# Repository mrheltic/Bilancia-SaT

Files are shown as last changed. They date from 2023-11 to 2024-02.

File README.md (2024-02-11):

# Bilancia SaT - Gruppo 04

This project uses Arduino and various libraries to create a weighing system with an HX711 load cell amplifier, an LCD display, and a tare button. The program continuously reads the change in weight and displays it on both the Serial Monitor and the LCD screen. We also implemented a tare button to reset the scale to zero when needed.

## Example

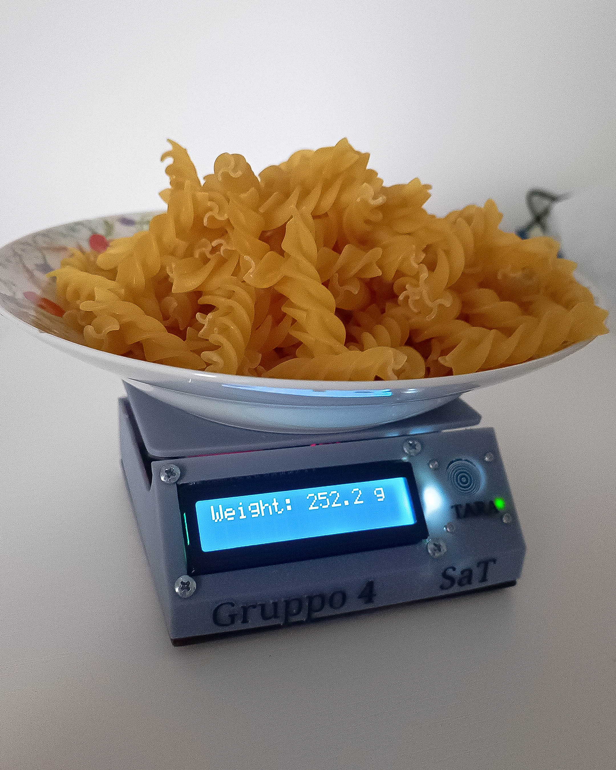
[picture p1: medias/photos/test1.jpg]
Example


## Assembly

https://github.com/mrheltic/Bilancia-SaT/assets/25135341/8b41f5b5-bcb0-4e01-b5df-058aa0fdd161

## Front View

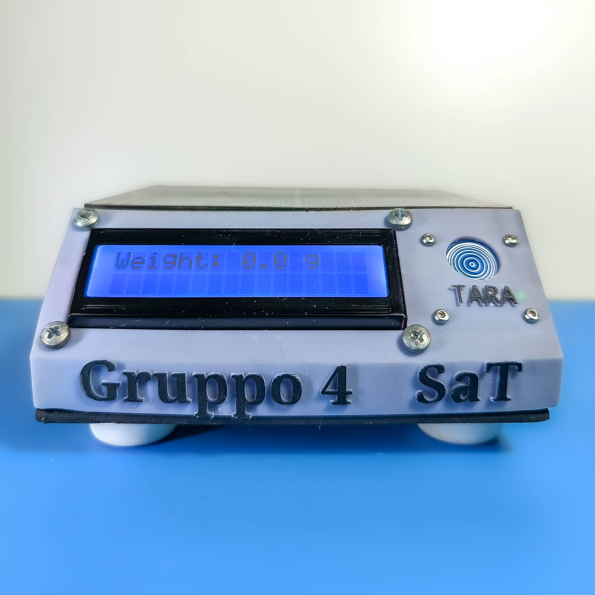
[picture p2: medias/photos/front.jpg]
Front View


## Top View

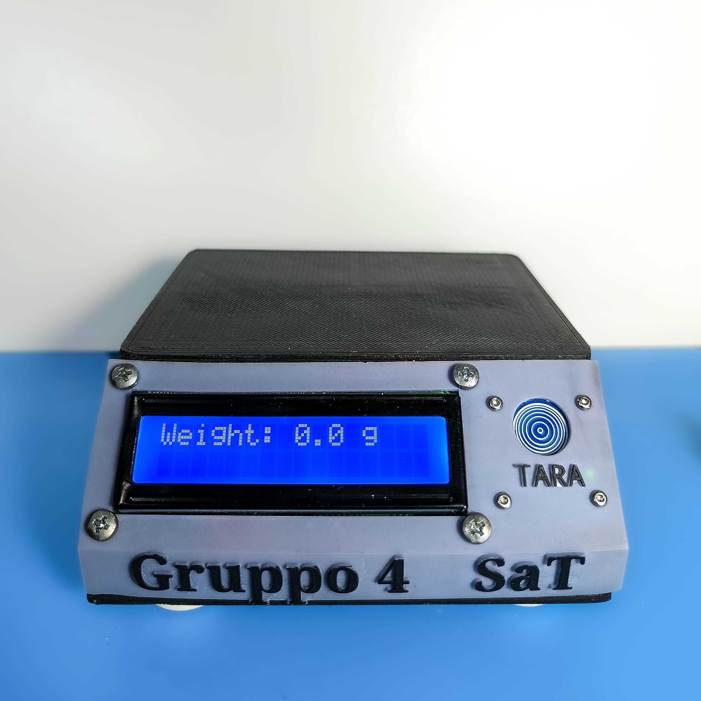
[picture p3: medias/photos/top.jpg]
Top View

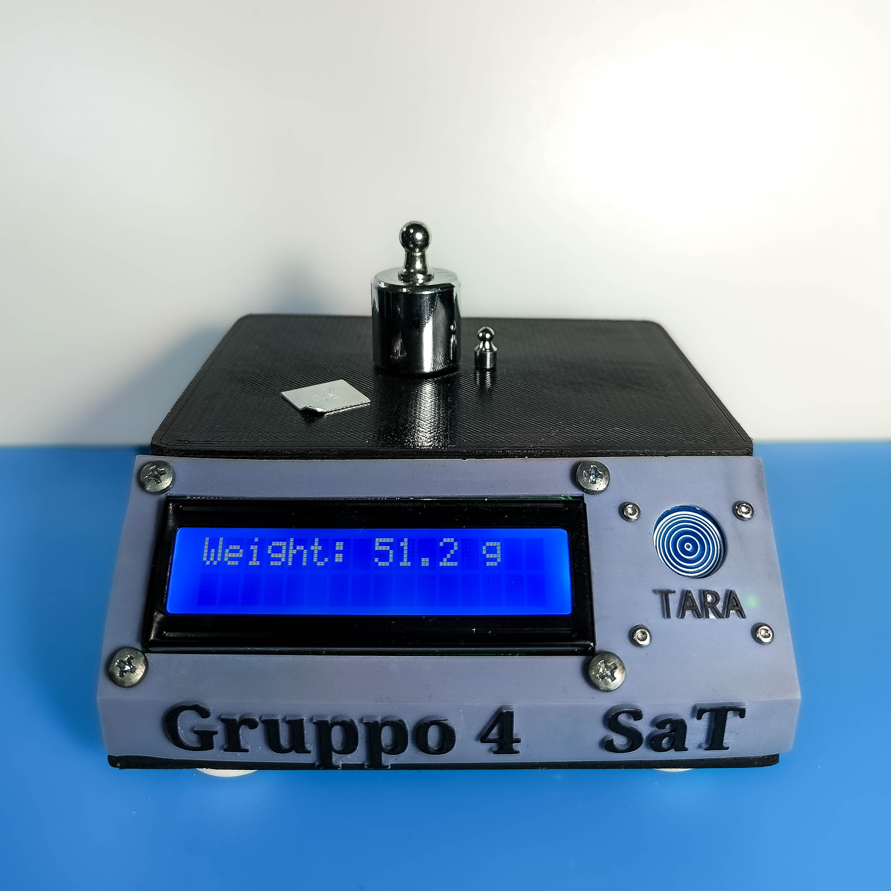
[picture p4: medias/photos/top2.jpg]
Top View with weights


## Bottom View

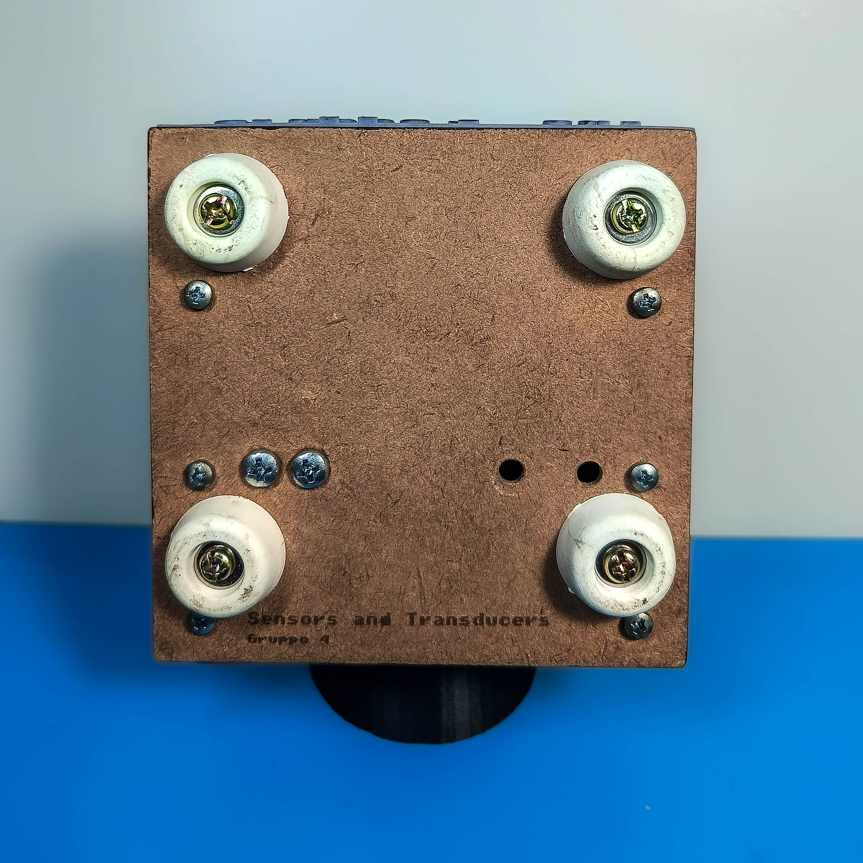
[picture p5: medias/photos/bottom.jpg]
Bottom View


## Side View

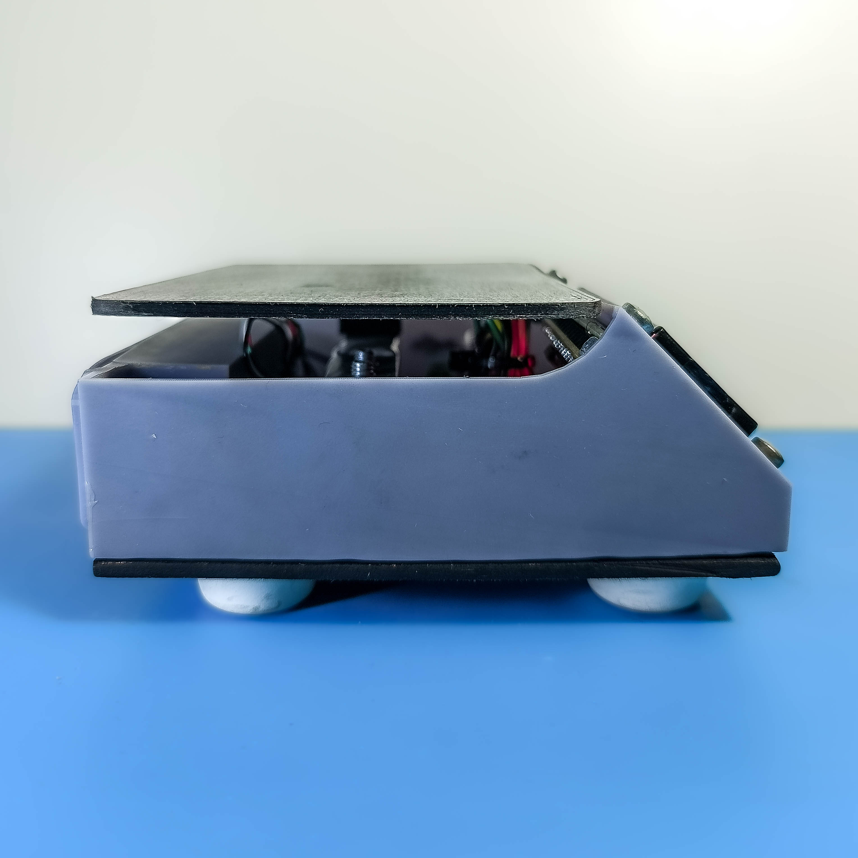
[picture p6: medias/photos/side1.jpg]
Side View

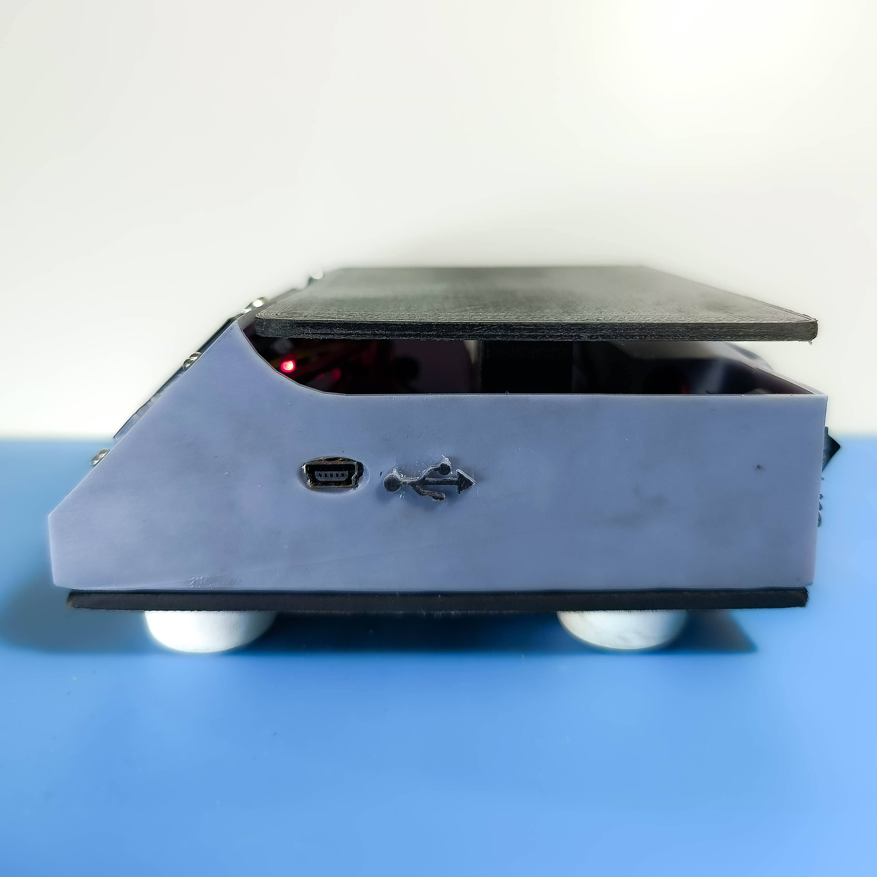
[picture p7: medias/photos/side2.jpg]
Side View


## Back View

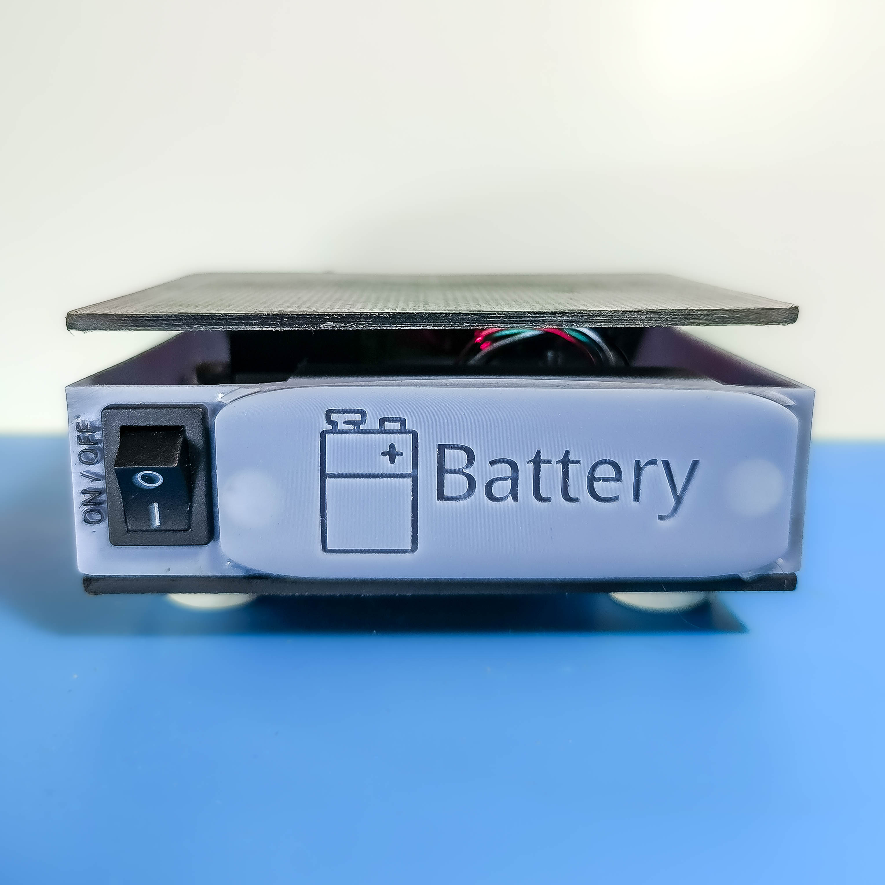
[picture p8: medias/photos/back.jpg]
Back View

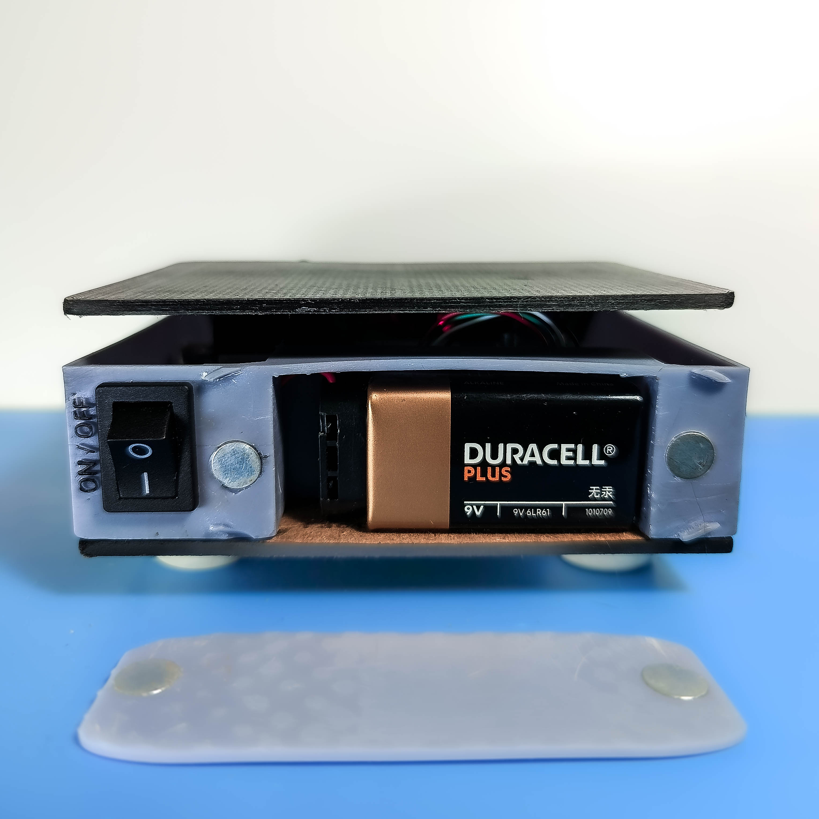
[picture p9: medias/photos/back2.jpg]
Back View with battery


# Components Used

<table>
  <tr valign="top" align=center>
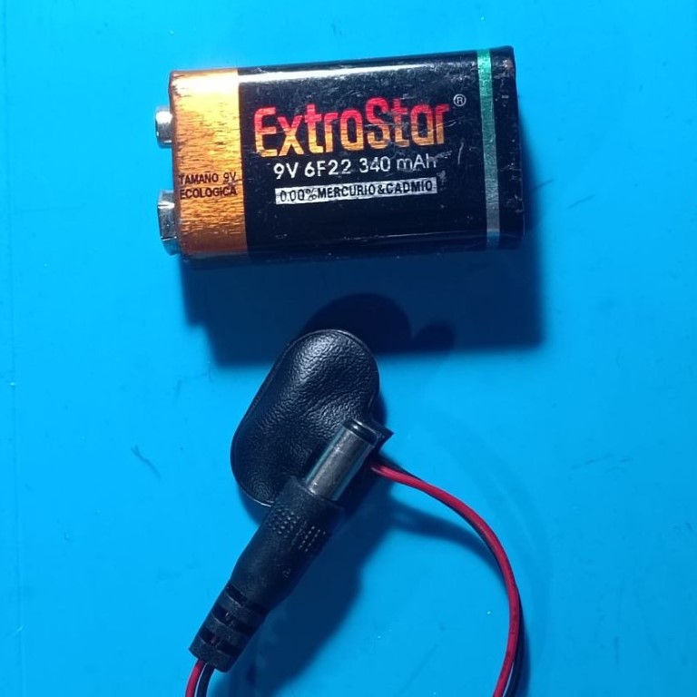
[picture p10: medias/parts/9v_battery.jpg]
9V Battery
    <td><br><strong>Battery 9V</strong><br>The 9V battery is used as a portable power source for the project.</td>
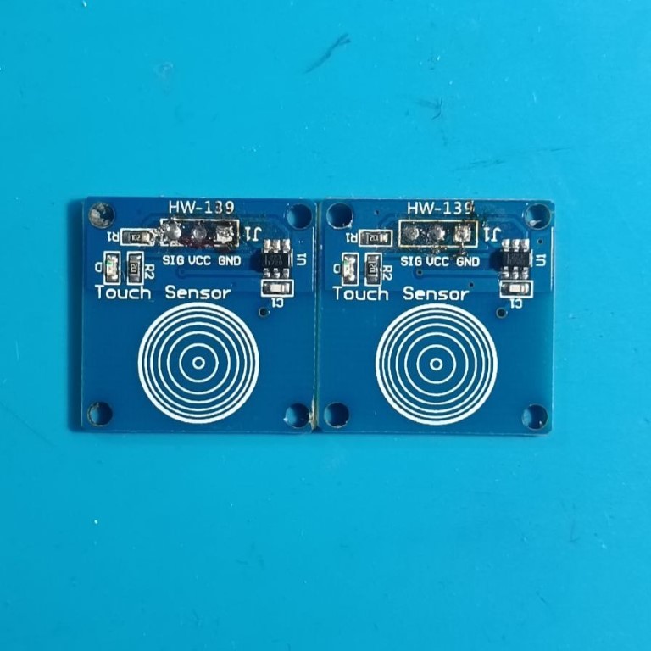
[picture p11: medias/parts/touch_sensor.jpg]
Touch button
    <td><br><strong>Touch Button (HW-139)</strong><br>The HW-139 touch button is a component used for touch detection. It can be used as a tare button for resetting the scale.</td>
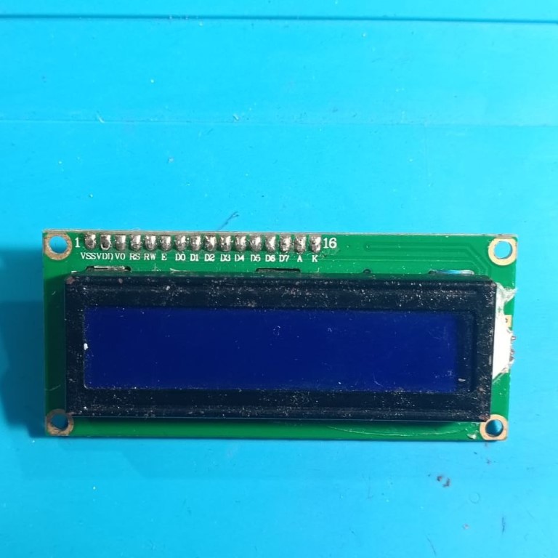
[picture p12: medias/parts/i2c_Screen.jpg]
16x2 Screen
    <td><br><strong>I2C 16x2 LCD Display</strong><br>The I2C 16x2 LCD display is used to show information such as the measured weight or other relevant details.</td>
  </tr>
  <tr valign="top" align=center>
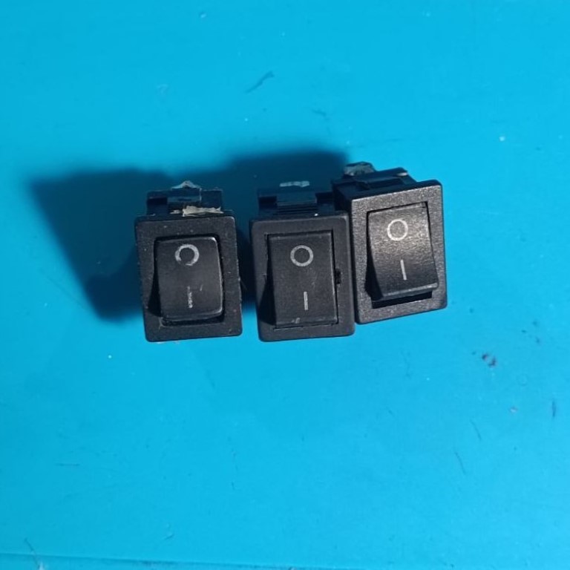
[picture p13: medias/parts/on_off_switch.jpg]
Switch
    <td><br><strong>ON-OFF Switch</strong><br>The ON-OFF switch is used to control the power supply to the circuit.</td>
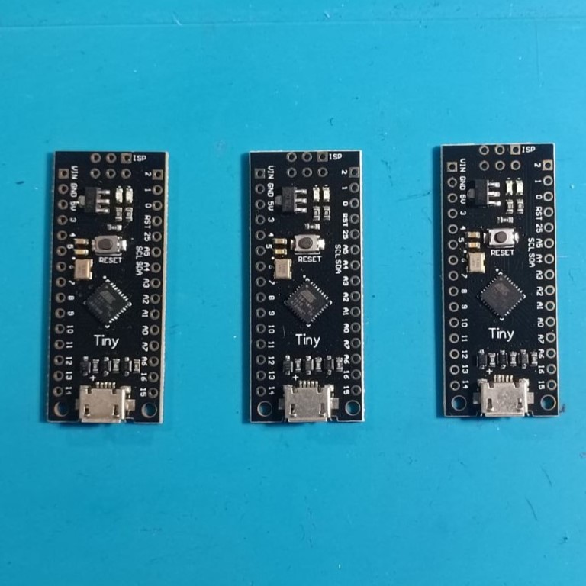
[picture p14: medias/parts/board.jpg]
Board
    <td><br><strong>ATtiny or Arduino Nano</strong><br>The ATtiny or Arduino Nano are some examples of a microcontroller development board used for programming and controlling the scale and its components.</td>
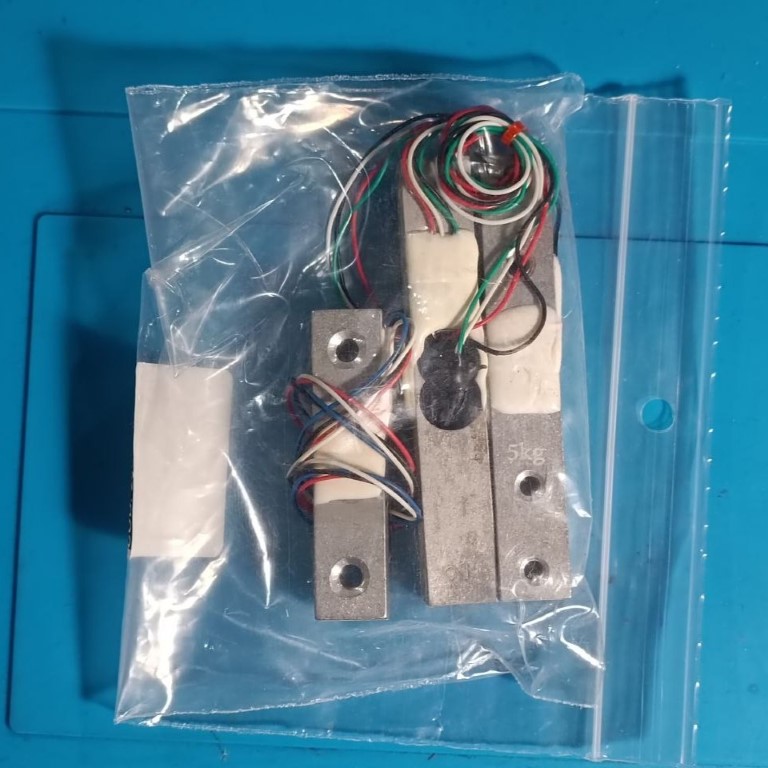
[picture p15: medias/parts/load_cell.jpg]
Load Cell
    <td><br><strong>5KG Load Cell</strong><br>The 5KG load cell is a weight sensor used to measure the weight of objects placed on the plate.</td>
  </tr>
  <tr valign="top" align=center>
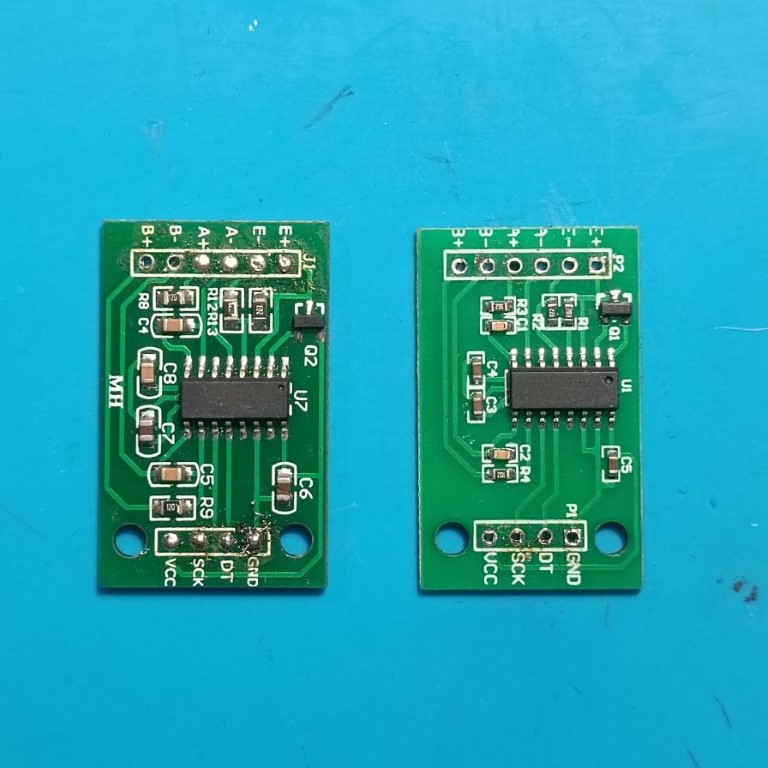
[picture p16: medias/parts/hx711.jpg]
HX711
    <td><br><strong>HX711</strong><br>The HX711 is used to amplify and convert the analog signal from the load cell into a digital one that can be read by the microcontroller.</td>
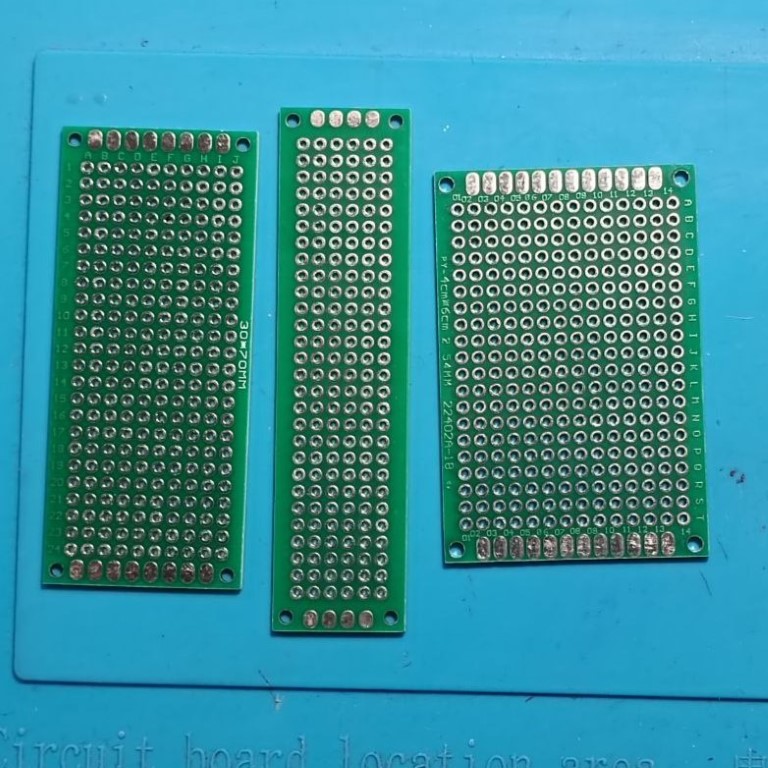
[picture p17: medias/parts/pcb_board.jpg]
PCB board
    <td><br><strong>PCB Board</strong><br>The PCB (Printed Circuit Board) is used to connect and organize the electronic components in the project.</td>
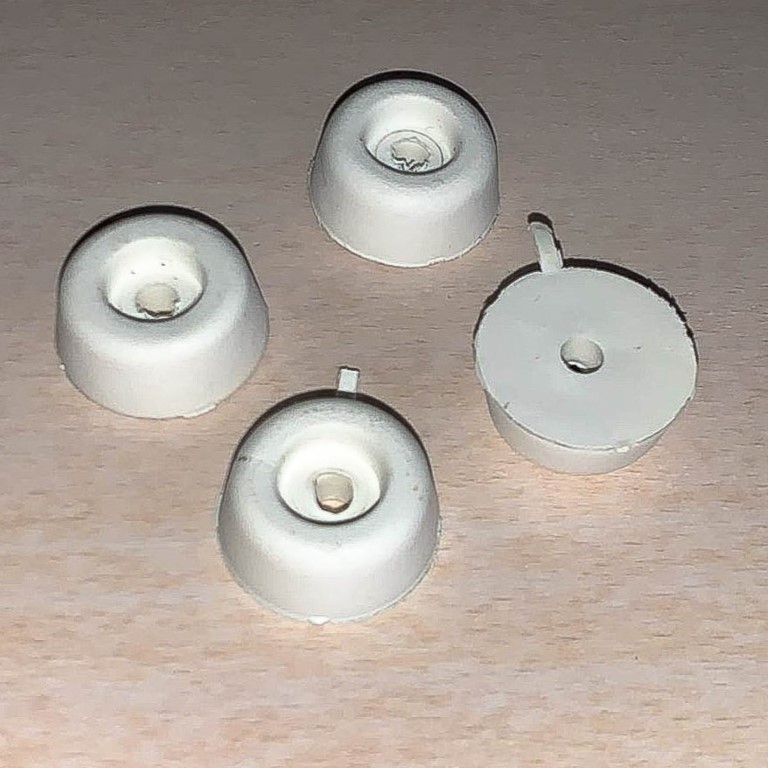
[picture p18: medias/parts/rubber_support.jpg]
Rubber support
    <td><br><strong>Rubber supports</strong><br>Rubber supports needed to avoid sliding and suport the structure of the scale.</td>
  </tr>
</table>

# Wiring
The components are wired as follows:

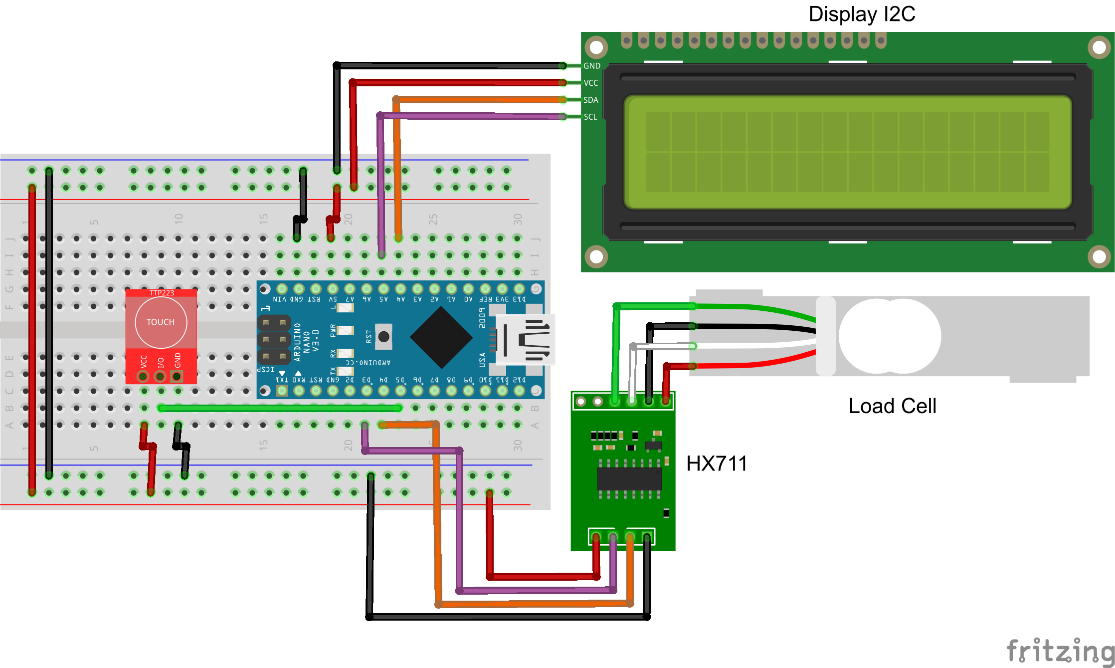
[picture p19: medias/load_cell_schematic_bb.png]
Schematic


HX711 load cell amplifier:
- LOADCELL_DOUT_PIN is connected to pin 4 of the Arduino board.
- LOADCELL_SCK_PIN is connected to pin 3 of the Arduino board.

LCD display (I2C interface):
- Address: 0x27
- Columns: 16
- Rows: 2

Tare button:
- Connect one terminal of the button to a digital input pin of the Arduino board.
- Connect the other terminal of the button to the ground (GND) pin of the Arduino board.
- Optionally, add a pull-up resistor between the digital input pin and the 5V pin of the Arduino board to ensure stable button readings. (We implemented it, if you want to add it, you can modify it in declaration part)

# Code

## Variables
The program uses the following variables:

- `calibration_factor`: This variable is used to calibrate the scale. It is a float value that can be adjusted based on the specific characteristics of the load cell and the desired measurement units.
- `units`: This variable stores the measured weight in grams.

## Setup
- Serial Monitor Initialization: The Serial Monitor is initialized with a baud rate of 115200.
- LCD Initialization: The LCD display is initialized using the above mentioned I2C address and the number of columns and rows.
- Button Initialization: The tare button pin is declared as an input, and if needed, a pull-up resistor is enabled.
- Scale Initialization: The HX711 scale is initialized with the specified data output pin and clock input pin.
- Raw Data Reading: The program reads the raw data from the scale using the `scale.read()` and `scale.read_average(20)` methods. This helps to determine the calibration factor.
- Calibration Factor Reading: The calibration factor is set using the `scale.set_scale()` method based on the raw data readings. The calibration factor adjusts the scale to provide accurate weight measurements.
- Tare Reading: The scale is tared using the `scale.tare()` method, which resets the scale to zero. This allows to measure the weight of objects neglecting the container's one.
- Serial and LCD Initialization Messages: Initialization messages are printed to the Serial Monitor and the LCD display to indicate that the setup process is completed.

## Main Loop
- Weight Measurement: The program continuously reads the change in weight using the `scale.get_units(10)` method. The 10 parameter represents the number of samples to average for a stable reading.
- LCD Output: The change in weight is displayed on the LCD screen by setting the cursor position and printing the weight value.
- Tare Functionality: If the tare button is pressed (HIGH state), the scale is tared again using the `scale.tare()` method. This allows for resetting the scale to zero when needed.
- Delay: The program waits for 100 milliseconds before reading the weight again. This delay helps to stabilize and to avoid rapid fluctuations of the measurements.

## Dependencies
The following libraries are required for this program to compile and run:

- Arduino.h: Provides the core Arduino functions and types.
- Wire.h: Enables communication with I2C devices.
- LiquidCrystal_I2C.h: Allows interfacing with I2C-based LCD displays.
- HX711.h: Provides the HX711 load cell amplifier functionality.

# 3D Printed parts

This project involves the creation of a scale using a combination of 3D-printed parts and electronic components. The modular design of the project allows for customization of the 3D-printed parts according to your specific needs.

## Parts Created

We have designed and printed several key parts for the scale, including:

<table border="0">
  <tr >
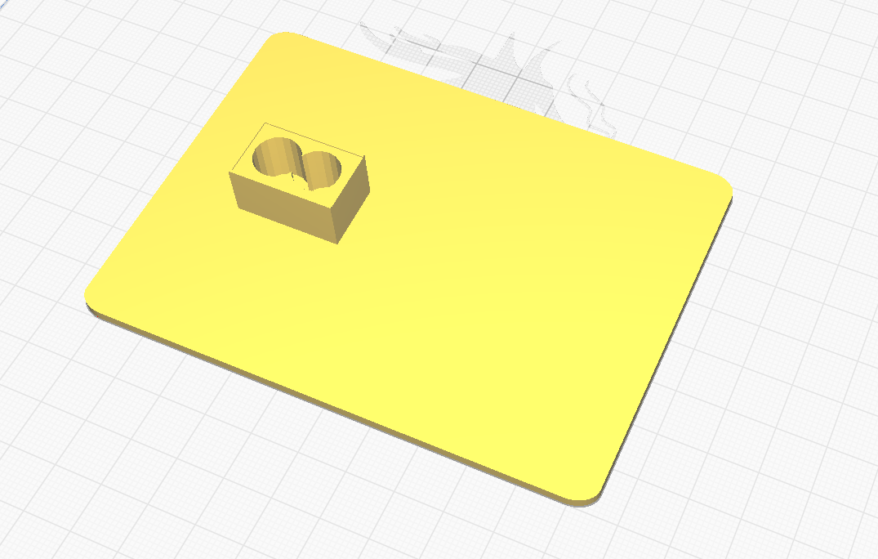
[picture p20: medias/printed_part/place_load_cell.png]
Platform
    <td></td>
    <td><p><b>Platform</b>: where the objects to be weighed are placed.</p></td>
  </tr>
  <tr>
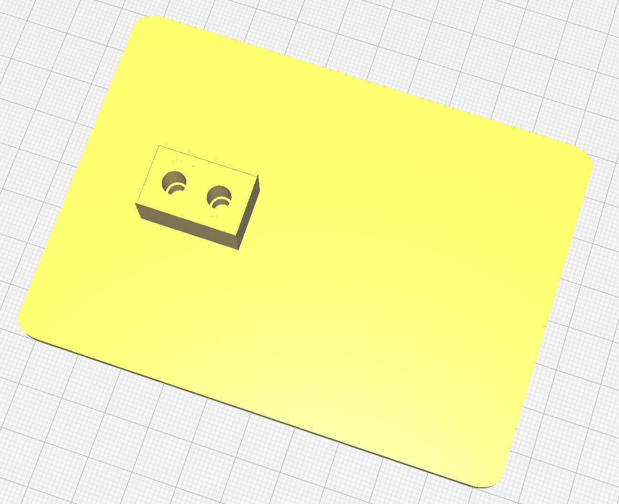
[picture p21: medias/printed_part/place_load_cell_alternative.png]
Alternative Platform
    <td></td>
    <td><p> <b>Alternative version of the Platform</b>: where the objects to be weighed are placed, with no screws in sight.</p></td>
  </tr>
  <tr>
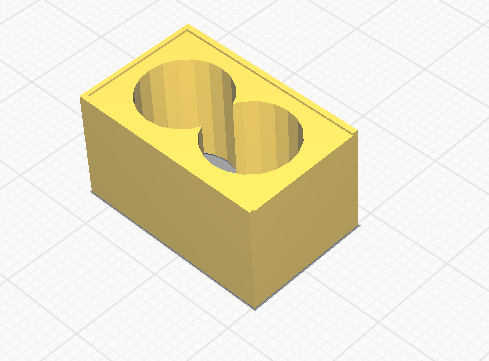
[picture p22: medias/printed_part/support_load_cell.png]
Support
    <td></td>
    <td><p><b>Load Cell Support</b>: securely holds the load cell in place.</p></td>
  </tr>
  <tr>
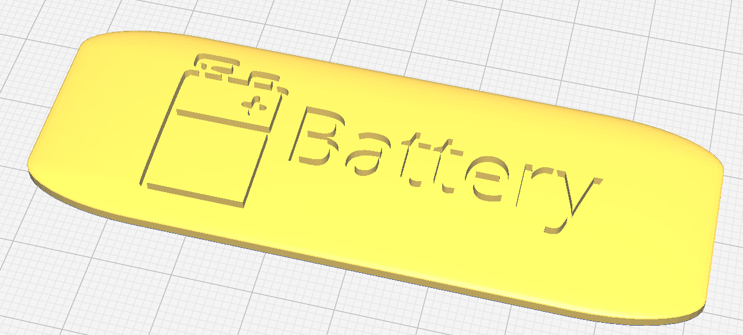
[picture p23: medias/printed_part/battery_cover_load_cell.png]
Battery
    <td></td>
    <td><p><b>Battery Cover</b>: to hide and protect the battery.</p></td>
  </tr>
  <tr>
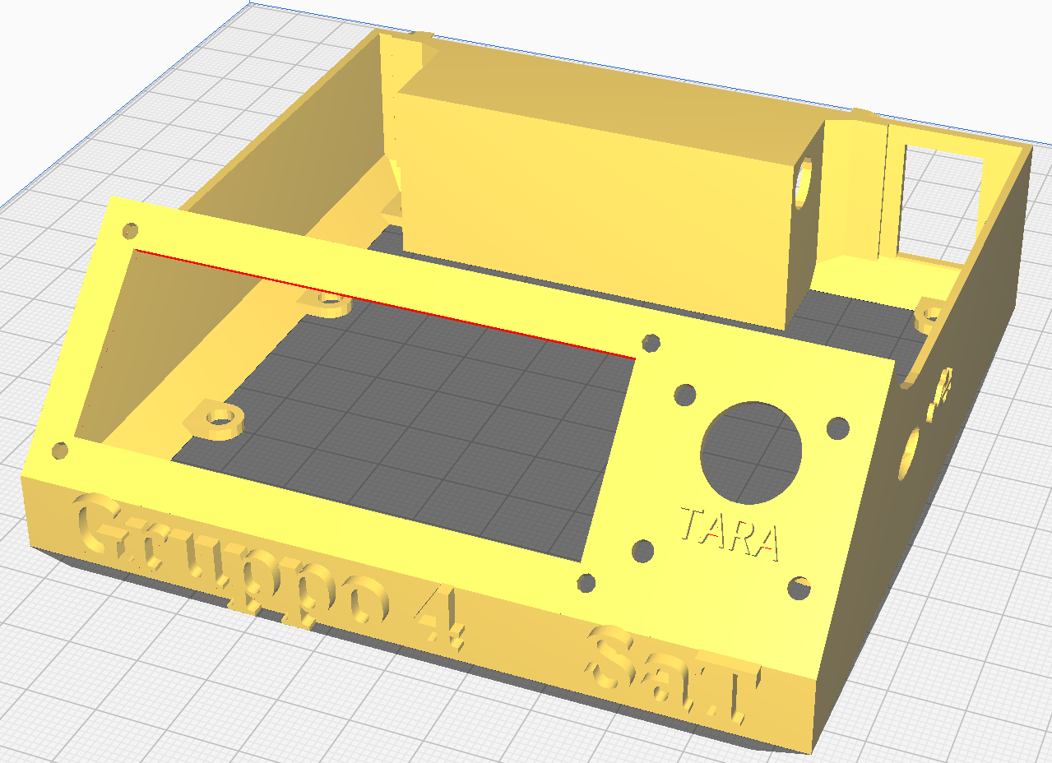
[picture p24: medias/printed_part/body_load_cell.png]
Body
    <td></td>
    <td><p><b>Body</b>: provides support to all the components and gives an aesthetically pleasing appearance.</p></td>
  </tr>
  <tr>
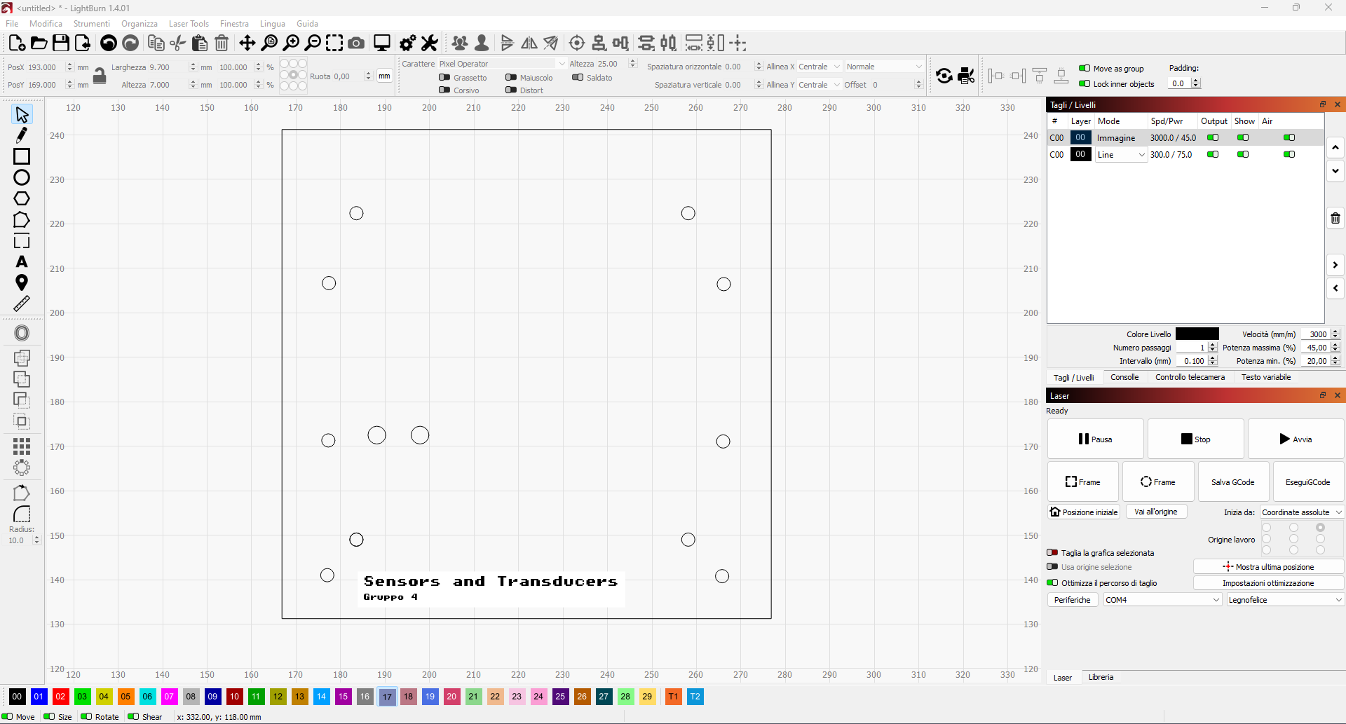
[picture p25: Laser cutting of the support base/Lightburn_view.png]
    <td></td>
    <td><p><b>Support base</b>: was made from a 4mm thick wooden board, which was cut and drilled by a laser engraver.</p></td>
  </tr>
</table>

-----

These 3D-printed parts have been carefully designed to ensure proper functionality and compatibility with the electronic components used in the project.

## Replicating the Project

If you are interested in recreating this scale project at home, you can easily replicate the 3D-printed parts by downloading the provided design files. Simply import the files into your preferred 3D modeling software and adjust them to fit your specific printer and requirements. Once you have the 3D-printed parts, you can follow the instructions in the project documentation to assemble and integrate the electronic components.

# Test

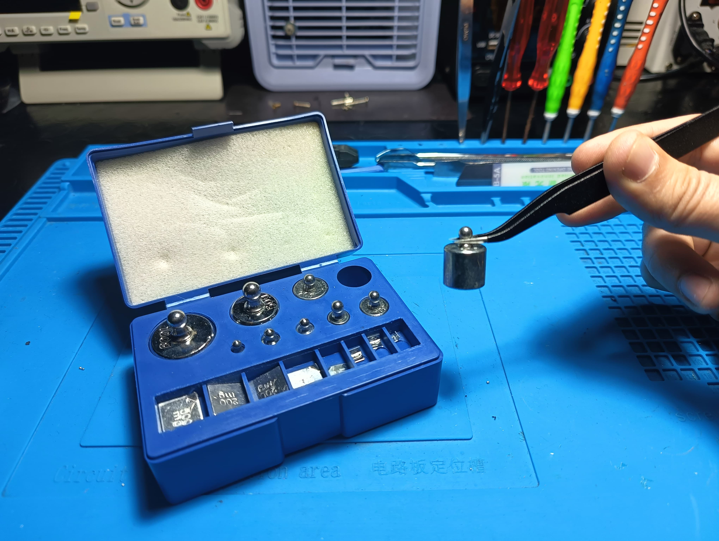
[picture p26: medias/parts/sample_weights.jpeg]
Sample Weights


## Calibration

We are trying to calibrate this scale using an iterative method to find the calibration factor and the offset that minimize the error between the actual weight and the measured weight. To do this, you can use the following formula:

$$
\text{Actual weight} = \text{Measured weight} \times \text{Cf} + \text{Offset}
$$

To calculate the error, we can use the following formula:

$$
\text{Error} = \sum_{i=1}^{n} (\text{Actual weight}_i - \text{Measured weight}_i \times \text{Cf} - \text{Offset})^2
$$

Where $n$ is the number of weights used in each iteration.

To find the Cf and the Offset that minimize the error, we use the gradient method, which consists of changing the values of Cf and Offset according to the derivative of the error with respect to them, using the following formulas:

$$
\text{New Cf} = \text{Cf} - \alpha \frac{\partial \text{Error}}{\partial \text{Cf}}
$$

$$
\text{New Offset} = \text{Offset} - \alpha \frac{\partial \text{Error}}{\partial \text{Offset}}
$$

Where $\alpha$ (also called learning rate) is a parameter that controls the convergence rate of the method. The value of $\alpha$ is chosen so that it is small enough to avoid swings, but large enough to reach the minimum in a few iterations.

To calculate the partial derivatives of the error, we need to use the following formulas:

$$
\frac{\partial \text{Error}}{\partial \text{Cf}} = -2 \sum_{i=1}^{n} (\text{Actual weight}_i - \text{Measured weight}_i \times \text{Cf} - \text{Offset}) \times \text{Measured weight}_i
$$

$$
\frac{\partial \text{Error}}{\partial \text{Offset}} = -2 \sum_{i=1}^{n} (\text{Actual weight}_i - \text{Measured weight}_i \times \text{Cf} - \text{Offset})
$$

In reality, for the calculation of Cf and offset, we are using an empirical formula, that is, adding the error with a certain weight to the previously calculated values:

$$
\text{New Cf} = \text{Cf} - \beta \times \text{Error}
$$

$$
\text{New Offset} = \text{Offset} - \beta \times \text{Error}
$$

Where $\beta$ is a kind of learning rate, suitably tuned to get progressively better results.

### Procedure

Wanting to go through the entire calibration process in depth:

- We prepared 6 iterations, with gradually smaller ranges, using sample weights:

| Iteration | Range | Increment |
|:---:|:-----:|:---:|
| 0 | 0g-100g | 10g |
| 1 | 0g-50g | 5g |
| 2 | 0g-5.5g | 0.5g |
| 3 | 0g-2g | 0.2g |
| 4 | 0g-0.5g | 0.05g |
| 5 | 0g-0.2g | 0.02g |

- We placed each weight for 5 points of the plate (center and the four corners)

- Using MATLAB, we used a regression algorithm to fit the collected data The slope of the regression line represents the calibration factor and the intercept represents the offset, using the Euclidean norm (norm 2) to evaluate the error.

- Last we used the data calculated by calibration, using it when compiling the microcontroller program.

### MATLAB pseudocode

```
clear the workspace and the screen
reset the serial devices
```

```
set the number of objects
create a matrix of zeros to store the measures
create two vectors of zeros to store the weights
```

```
create and open a serial connection with the scale
```
```
wait until the scale is ready
```
```
for each object
    print a new line
    for each position from 1 to 5
        if the position is 1 (middle)
            ask the user to enter the known weight and place the object in the middle
            validate the input
            store the known weight in the vector x
            print a new line
        else if the position is 2 (bottom left)
            ask the user to place the object in the bottom left
        else if the position is 3 (top left)
            ask the user to place the object in the top left
        else if the position is 4 (top right)
            ask the user to place the object in the top right
        else if the position is 5 (bottom right)
            ask the user to place the object in the bottom right
        send a signal to the scale
        read the measured value from the scale
        store the measured value in the matrix measures
        print the measured value
    end for
end for
```

```
close and delete the serial connection
reset the serial devices
```
```
for each object
    calculate the average of the measures for that object
    store the average in the vector y
end for
```
```
create a table with the vectors x and y
save the table as a text file
save the table as a csv file
```
```
find the coefficients of the best fitting line for the data
the slope is the calibration factor
the intercept is the offset
evaluate the line at the known weights
compute the error vector
compute the error norm
print the error
```
```
create and clear a figure
plot the data as green circles
plot the line as a solid line
```

### Stop condition

For calibration, we have to find the right compromise to make the regression line fit, considering that we have to use a smaller and smaller range of weights until we arrive at a measurement that is not fouled by noise in such a way that the behavior of the scale is no longer linear. We found that up to the third iteration we still have linear behavior, with a larger error than in the second iteration, as the distance between the points and the line increases. Using a smaller range would mean that the measurements are greatly affected by noise, increasing the error as we try to fit a line into a nonlinear set of points.

#### Iteration n. 0

<table border="0">
  <tr>
    <td align="center">
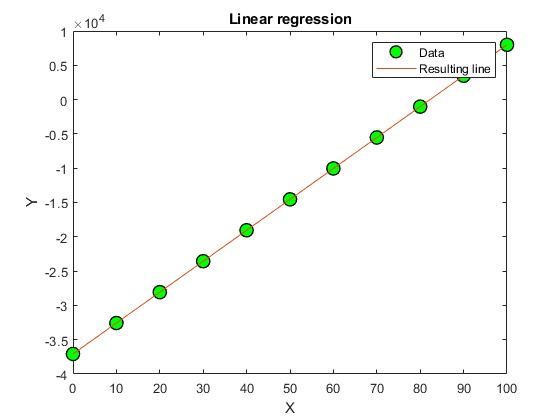
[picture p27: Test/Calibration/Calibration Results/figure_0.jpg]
Iteration 0
      
    </td>
    <td align="center">
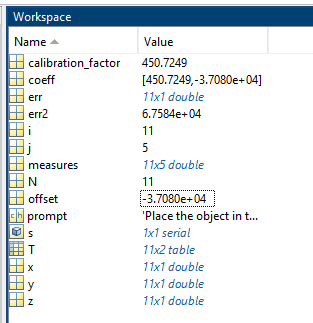
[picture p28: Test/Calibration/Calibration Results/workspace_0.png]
Workspace 0
      
    </td>
  </tr>
</table>

------

#### Iteration n. 1

<table border="0">
  <tr>
    <td align="center">
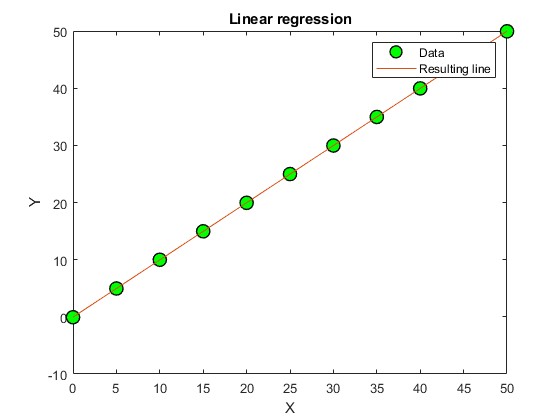
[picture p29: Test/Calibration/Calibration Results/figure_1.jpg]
Iteration 1
      
    </td>
    <td align="center">
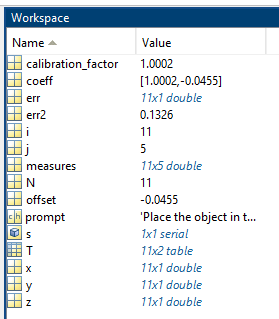
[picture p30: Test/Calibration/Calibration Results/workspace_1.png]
Workspace 1
      
    </td>
  </tr>
</table>

------

#### Iteration n. 2

<table border="0">
  <tr>
    <td align="center">
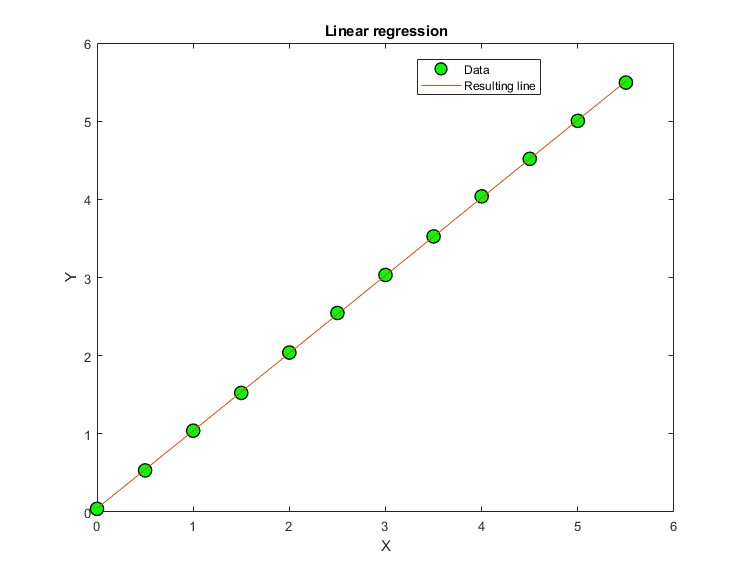
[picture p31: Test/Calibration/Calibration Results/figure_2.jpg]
Iteration 2
      
    </td>
    <td align="center">
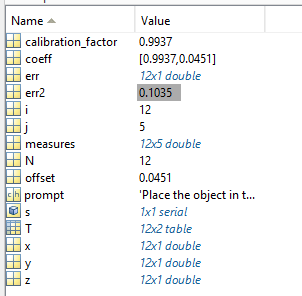
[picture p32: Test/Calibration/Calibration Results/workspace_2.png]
Workspace 2
      
    </td>
  </tr>
</table>

------

#### Iteration n. 3

<table border="0">
  <tr>
    <td align="center">
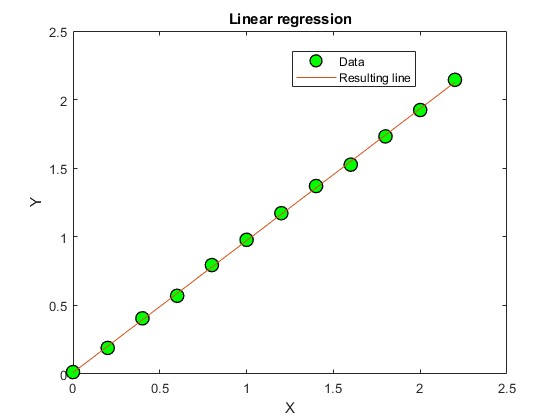
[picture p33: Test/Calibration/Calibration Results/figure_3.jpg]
Iteration 3
      
    </td>
    <td align="center">
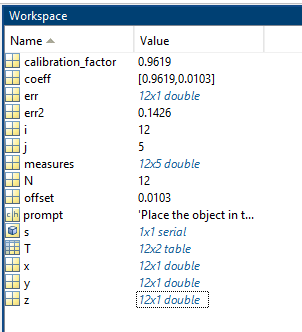
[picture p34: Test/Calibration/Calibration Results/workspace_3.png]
Workspace 3
      
    </td>
  </tr>
</table>

------

#### Iteration n. 4

<table border="0">
  <tr>
    <td align="center">
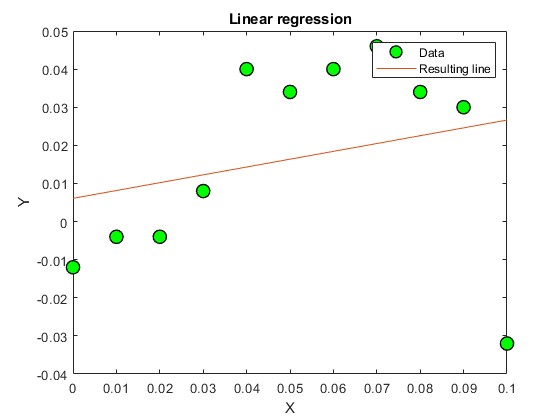
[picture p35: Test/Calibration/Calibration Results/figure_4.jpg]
Iteration 4
      
    </td>
    <td align="center">
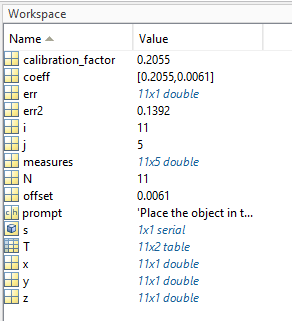
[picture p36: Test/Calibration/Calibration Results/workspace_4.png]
Workspace 4
      
    </td>
  </tr>
</table>

> [!NOTE]
> In this graph, it can be seen that variations on the order of hundredths of a gram are not appreciable, as the noise mat is of the same order of magnitude, so it makes the regression results much worse when calculating Cf and offset. Taken this into account, the 5th iteration wouldn't have much meaning.

------

### Results

In truth, already the first iteration returns us a plausible value of Cf, but this can be further improved. The same applies to the offset as well. The best result was achieved at the second iteration, when the range of values is small, but the variations between weights are still appreciable. In addition, we noticed that when the variation falls below 0.5 grams it starts to feel particularly noisy, so the measurements are more degraded. This, counterintuitively gives worse results, and as can be seen from the third iteration, will give a larger error and worse Cf and offset values than those calculated before.

## Noise

The purpose of the noise test was to evaluate the accuracy and stability of the balance without any weights on it. We expected the balance to output zero or very small values when no weight was applied. However, due to various sources of noise, such as electrical interference, mechanical vibrations, or environmental factors, the balance might output some non-zero values.

To perform the noise test, we collected 100 samples from the balance using Matlab, receiving a floating-point number representing the weight in grams from the scale. We repeated this process 100 times and stored the values in a vector n. We also saved the data in a table T and exported it to a text file and a csv file.

We then analyzed the data using Matlab. We calculated the mean and the standard deviation of the vector n to get an estimate of the average noise level and the noise variance. We also plotted the frequency spectrum of the vector n using the discrete Fourier transform (DFT) to identify any dominant frequency components in the noise.

The results of the noise test are shown below. The mean of the vector n is 0.12 g and the standard deviation is 0.07 g. This means that the balance has a very low noise level and a high accuracy. The frequency spectrum of the vector n shows that the noise is mostly random and does not have any significant peaks. This means that the balance is stable and does not suffer from any periodic disturbances.

### MATLAB pseudocode

```
clear the workspace and the screen
reset the serial devices
```
```
Set N to 100
Create a vector of N elements, initialized to zero
```

```
create and open a serial connection with the scale
```
```
wait until the scale is ready
```
```
For each element of the vector
    Receive a numeric value from the device
    Save the value in the vector and print it on the screen
End for
```
```
Compute the DFT
```
```
Compute the mean and the standard deviation of the original vector
```

## Repeatability

Like any instrument, electronic scales can suffer from repeatability problems. This means that when the same load is measured multiple times, the result is not always exactly the same. To find out the repeatability of the instrument, a repeatability test is performed.

The repeatability test is performed by replacing the same load at the same point on the weighing plane (to avoid any eccentricity error) several times. The test must be performed under identical and constant conditions and with identical handling.

The calibration weight used should have a size as close as possible to the maximum range of the instrument. Often a repeatability test is performed with a single load, but it can also be performed with different load values, separately.

A repeatability test is normally performed by repeating the measurement at least 5 times in a row. We did two tests:

<table>
  <tr>
    <td align="center">
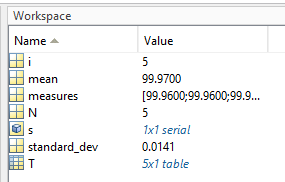
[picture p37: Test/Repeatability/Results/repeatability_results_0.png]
      
      <p><b>100g</b></p>
      <p>mean: 99.97g</p>
      <p>stdev: 0.0141</p>
    </td>
    <td align="center">
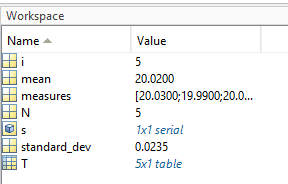
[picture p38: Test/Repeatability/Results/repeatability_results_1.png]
      
      <p><b>20g</b></p>
      <p>mean: 20.02g</p>
      <p>stdev: 0.0235</p>
    </td>
  </tr>
</table>

------

In the repeatability test, the instrument is first zeroed, then the load is placed on the plate and the indication is recorded once stabilized. Then the load is removed and the zero indication is checked and zeroed if necessary. Then the load is replaced and so on. For a scale with multiple fields / divisions, a test weight below the first range should be sufficient.

### MATLAB pseudocode

```
clear the workspace and the screen
reset the serial devices
```
```
Set N to 5
Create a vector of N elements, initialized to zero
Ask the user to remove any object from the scale
```

```
create and open a serial connection with the scale
```
```
wait until the scale is ready
```
```
For each element of the vector
    Ask the user to place the object on the scale
    Receive a numeric value from the device
    Save the value in the vector and print it on the screen
    Ask the user to remove the object from the scale
End for
```
```
Close and delete the serial connection
```
```
Compute the mean and the standard deviation of the original vector
```

## Eccentricity

Eccentricity tests are performed on weighing instruments to measure how the position of the load affects the accuracy and repeatability of the readings. The principle of the test is to compare the indications of the instrument when the same load is applied at different locations on the load receptor. The locations are chosen according to the shape and the number of support points of the load receptor, following the standards OIML R76 and EN 45501. The test load should be at least one third of the maximum capacity of the instrument, and preferably a single load, to ensure the consistency of the center of gravity.

<p align=center>
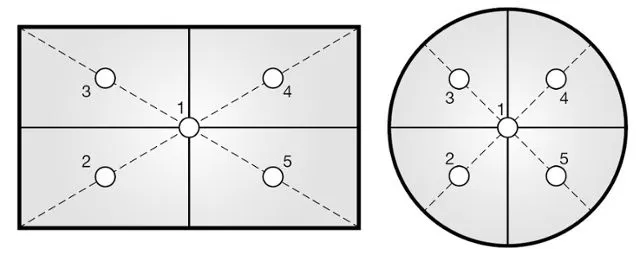
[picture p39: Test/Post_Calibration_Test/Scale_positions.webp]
Positions

</p>

The test procedure consists of placing the test load at the center of the load receptor and recording the indication. Then, the load is moved to four other locations, usually at the corners or the edges of the load receptor, and the indications are recorded again. The load is then returned to the center and the indication is checked for any drift. The zero of the instrument may be verified and adjusted between each location, if needed. Alternatively, the instrument may be tared when the load is at the center, to make the differences between locations more visible.

<table>
  <tr>
    <td >
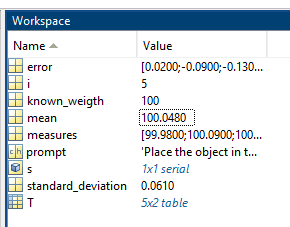
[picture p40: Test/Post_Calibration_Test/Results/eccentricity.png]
Eccentricity
      
    </td>
    <td>
      <p>
      The test is considered passed if the differences between the indications at different locations are within the permissible errors specified by the standards or the manufacturer. The differences are also used to calculate the eccentricity error, which is the maximum deviation of the indication from the arithmetic mean of all indications. The eccentricity error is an important parameter to evaluate the performance and the quality of the weighing instrument.
      </p>
    </td>
  </tr>
</table>

### MATLAB pseudocode

```
clear the workspace and the screen
reset the serial devices
```
```
Set N to 5
Create a vector of N elements, initialized to zero
Ask the user to remove any object from the scale
```

```
create and open a serial connection with the scale
```
```
wait until the scale is ready
```
```
For each position of the scale
    Ask the user to place the object on the scale
    Receive a numeric value from the device
    Save the value in the vector and print it on the screen
    Ask the user to remove the object from the scale
End for
``` 
```
Close and delete the serial connection
```
```
Compute the mean and the standard deviation of the original vector
```
```
Save the data in a table with two columns: measured weight and error
```

## Hysteresis

Hysteresis refers to the difference in a system’s output when a specific input is approached from increasing and decreasing directions. In weighing tests, it’s crucial not to overshoot or undershoot the load to accurately identify hysteresis. The instrument should be calibrated with increasing and decreasing points, approaching each test point with increasing or decreasing weight respectively.

Multiple points throughout the instrument’s measurement range are used to reveal any linearity issues, which means the instrument does not measure equally accurate throughout its range. Even if the zero and full span are correct, there may be errors in the middle of the range, referred to as linearity errors, or non-linearity.

The purpose of a weighing test is to test the calibrated accuracy of the weighing instrument across its entire range, in several steps, with increasing and decreasing weight. Typically, 5 to 10 different loads (test points) are used, and each range must be calibrated separately in multi-range instruments.

### MATLAB pseudocode

```
clear the workspace and the screen
reset the serial devices
```
```
Set N to 5
Create a vector of 2*N elements, initialized to zero
Ask the user to remove any object from the scale
```

```
create and open a serial connection with the scale
```
```
wait until the scale is ready
```
```
For each measurement, up to N
    ask the user to enter the known weight (ascending order)
    Receive a numeric value from the device
    Save the value in the vector and print it on the screen
    Ask the user to remove the object from the scale
End for
``` 
```
For each measurement, for N+1 up to 2*N
    ask the user to enter the known weight (descending order)
    Receive a numeric value from the device
    Save the value in the vector and print it on the screen
    Ask the user to remove the object from the scale
End for
``` 
```
Close and delete the serial connection
```
```
plot the data
```

> [!NOTE]
> Try not to keep the scale turned on for a very long time, since it may lose precision due to the heating of the components.

# Further Improvements
- You can modify the calibration factor (`calibration_factor`) to adjust the scale according to your specific load cell and measurement requirements.
- By using the purple hx711, that has bigger and more separated tracks, it is possible to benefit from an improvement in terms of precision, since the entity of the disturbances is smaller. 

<p align=center>
 Purple Hx711
<p>

- The program can be extended to support different measurement units by adding appropriate conversions and displaying the result in the desired unit on the LCD screen.
- Error handling and validation can be implemented to handle exceptional cases, such as when the load cell is not connected or when the measurements are out of range, making them block the execution of the entire program.
- You can compile this code to run also on other boards that are better for 3D printed cases (actually tested on Arduino Uno, ESP8266)

# Repo Activity

Repobeats analytics image

# License
This project is licensed under the GPLv3 license.

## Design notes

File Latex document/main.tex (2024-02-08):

% Impostazioni e installazione dei pacchetti (NON MODIFICARE) 
\documentclass{01-Impostazioni/dandcSetting}
\usepackage{01-Impostazioni/package}   

\usepackage[italian]{babel}

% Informazioni personali (da modificare)
\newcommand{\titolo}{Bilancia SaT - Gruppo 04}
\newcommand{\studenti}{Vincenzo Pio Florio \\ Francesco Stasi\\ Davide Tonti \\ Simona Vatinno \\ Giovanni Zito}
\newcommand{\tutor}{Prof. Ing. Adamo Francesco, PhD}
\newcommand{\materia}{Sensors and Transducers}
\newcommand{\corsodilaurea}{LAUREA MAGISTRALE IN INGEGNERIA DELL'AUTOMAZIONE}
\newcommand{\dipartimento}{DIPARTIMENTO DEI}
\newcommand{\annoaccademico}{ANNO ACCADEMICO 2023-2024}

%%
%%%%%%%%%%%%%%%%%%%%%%%%%%%%%%%%%%%%%%%%%%%%%%%%%%%%%%%%%%%%%%%
%%
%%
%%%%%%%%%%%%%%%%%%%%%%%%%%%%%%%%%%%%%%%%%%%%%%%%%%%%%%%%%%%%%%%
% FRONTESPIZIO (NON MODIFICARE) 

\begin{document}
\maketitle

\newpage
\tableofcontents
\newpage
%%%%%%%%%%%%%%%%%%%%%%%%%%%%%%%%%%%%%%%%%%%%%%%%%%%%%%%%%%%%%%%
%%
%%%%%%%%%%%%%%%%%%%%%%%%%%%%%%%%%%%%%%%%%%%%%%%%%%%%%%%%%%%%%%%
% INIZIO DEL DOCUMENTO
\cleardoublepage

\pagenumbering{arabic}
\setcounter{page}{1}

\include{sections/0-Introduction}
\include{sections/1-Components Used}
\include{sections/2-Wiring}
\include{sections/3-Code}
\include{sections/4-PrintedParts}
\include{sections/5-Test}
\include{sections/6-FurtherImprovements}
\include{sections/7-Credits}

\clearpage

%%%%%%%%%%%%%%%%%%%%%%%%%%%%%%%%%%%%%%%%%%%%%%%%%%%%%%%%%%%%%%%
%% FINE DEL DOCUMENTO
%%
%%
%%
%%%%%%%%%%%%%%%%%%%%%%%%%%%%%%%%%%%%%%%%%%%%%%%%%%%%%%%%%%%%%%%
% STAMPA DELLA BIBLIOGRAFIA (NON MODIFICARE
%\printbibliography[heading=bibintoc,title={Riferimenti}]
%\printbibliography[heading=bibintoc,title={References}] % Per tesina in inglese decommentare

%%%%%%%%%%%%%%%%%%%%%%%%%%%%%%%%%%%%%%%%%%%%%%%%%%%%%%%%%%%%%%%
% Appendice
%\appendix

%%%%%%%%%%%%%%%%%%%%%%%%%%%%%%%%%%%%%%%%%%%%%%%%%%%%%%%%%%%%%%%
%%
%%
%%
%%%%%%%%%%%%%%%%%%%%%%%%%%%%%%%%%%%%%%%%%%%%%%%%%%%%%%%%%%%%%%%
\end{document}
% FINE

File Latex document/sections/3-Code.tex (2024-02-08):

\section{Code}

\subsection{Variables}
The program uses the following variables:
\begin{itemize}
\item \texttt{calibration\_factor}: This variable is used to calibrate the scale. It is a float value that can be adjusted based on the specific characteristics of the load cell and the desired measurement units.
\item \texttt{units}: This variable stores the measured weight in grams.
\end{itemize}

\subsection{Setup}
\begin{itemize}
\item Serial Monitor Initialization: The Serial Monitor is initialized with a baud rate of 115200.
\item LCD Initialization: The LCD display is initialized using the above mentioned I2C address and the number of columns and rows.
\item Button Initialization: The tare button pin is declared as an input, and if needed, a pull-up resistor is enabled.
\item Scale Initialization: The HX711 scale is initialized with the specified data output pin and clock input pin.
\item Raw Data Reading: The program reads the raw data from the scale using the \texttt{scale.read()} and \texttt{scale.read\_average(20)} methods. This helps to determine the calibration factor.
\item Calibration Factor Reading: The calibration factor is set using the \texttt{scale.set\_scale()} method based on the raw data readings. The calibration factor adjusts the scale to provide accurate weight measurements.
\item Tare Reading: The scale is tared using the \texttt{scale.tare()} method, which resets the scale to zero. This allows to measure the weight of objects neglecting the container's one.
\item Serial and LCD Initialization Messages: Initialization messages are printed to the Serial Monitor and the LCD display to indicate that the setup process is completed.
\end{itemize}

\subsection{Main Loop}
\begin{itemize}
\item Weight Measurement: The program continuously reads the change in weight using the \texttt{scale.get\_units(10)} method. The 10 parameter represents the number of samples to average for a stable reading.
\item LCD Output: The change in weight is displayed on the LCD screen by setting the cursor position and printing the weight value.
\item Tare Functionality: If the tare button is pressed (HIGH state), the scale is tared again using the \texttt{scale.tare()} method. This allows for resetting the scale to zero when needed.
\item Delay: The program waits for 100 milliseconds before reading the weight again. This delay helps to stabilize and to avoid rapid fluctuations of the measurements.
\end{itemize}

\subsection{Dependencies}
The following libraries are required for this program to compile and run:
\begin{itemize}
\item Arduino.h: Provides the core Arduino functions and types.
\item Wire.h: Enables communication with I2C devices.
\item LiquidCrystal\_I2C.h: Allows interfacing with I2C-based LCD displays.
\item HX711.h: Provides the HX711 load cell amplifier functionality.
\end{itemize}

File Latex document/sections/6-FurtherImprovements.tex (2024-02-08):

\section{Further Improvements}

\begin{itemize}
    \item You can modify the calibration factor $(calibration\_factor)$ to adjust the scale according to your specific load cell and measurement requirements.
    \item By using the purple hx711, that has bigger and more separated tracks, it is possible to benefit from an improvement in terms of precision, since the entity of the disturbances is smaller.
    
    \begin{figure}[H]
    \centering
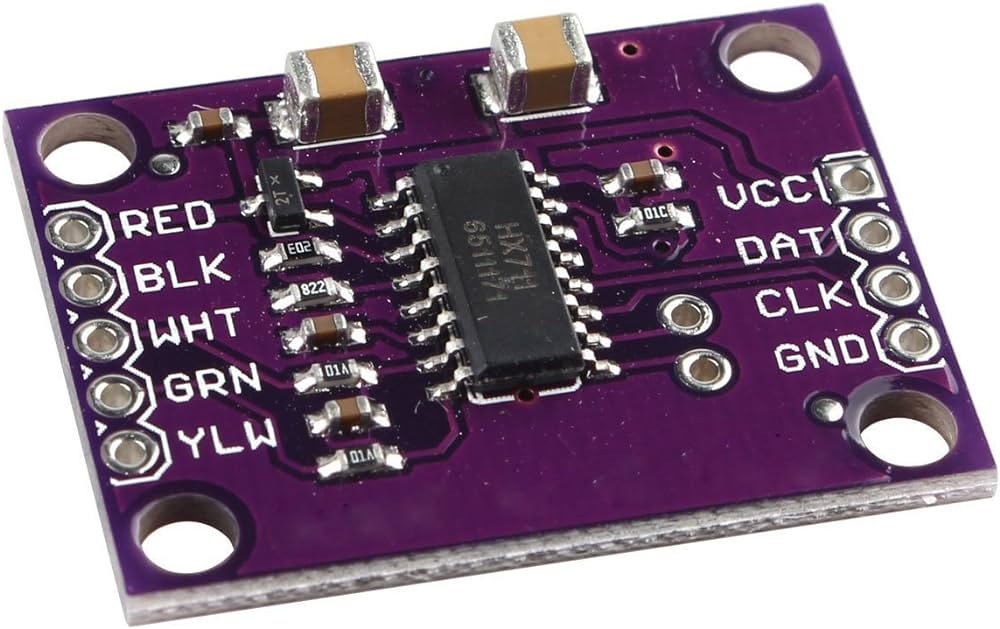
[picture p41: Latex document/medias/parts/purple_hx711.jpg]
    
    \caption{Purple HX711}
    \label{fig:purplehx711}
    \end{figure}
    \noindent

    \item The program can be extended to support different measurement units by adding appropriate conversions and displaying the result in the desired unit on the LCD screen.
    \item Error handling and validation can be implemented to handle exceptional cases, such as when the load cell is not connected or when the measurements are out of range, making them block the execution of the entire program.
    \item You can compile this code to run also on other boards that are better for 3D printed cases (actually tested on Arduino Uno, ESP8266)
\end{itemize}

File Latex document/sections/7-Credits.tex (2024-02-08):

\section{Credits}

\begin{itemize}
\item \textbf{Modellazione 3D}: Stasi
\item \textbf{Incisione laser del piatto}: Stasi
\item \textbf{Stampa 3D Resina}: Stasi
\item \textbf{Stampa 3D PLA}: Vatinno
\item \textbf{Assemblaggio e progettazione PCB}: Stasi, Tonti, Vatinno, Zito
\item \textbf{Codici Arduino}: Florio, Stasi, Tonti, Vatinno, Zito
\item \textbf{Codici Matlab}: Florio, Stasi, Vatinno
\item \textbf{Cura della repository e media presentazione}: Florio, Stasi, Vatinno, Zito
\item \textbf{Organizzazione ambiente di lavoro}: Florio
\item \textbf{Relazione LaTeX}: Florio, Tonti, Zito
\item \textbf{Matlab APP}: Vatinno, Zito
\end{itemize}

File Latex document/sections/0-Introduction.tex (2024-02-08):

  \section{Introduction}
This project uses Arduino and various libraries to create a weighing system with an HX711 load cell amplifier, an LCD display, and a tare button. The program continuously reads the change in weight and displays it on both the Serial Monitor and the LCD screen. We also implemented a tare button to reset the scale to zero when needed.

\begin{figure}[H]
    \centering
    
    \caption{Test with some pasta}
    \label{fig:immagine}
\end{figure}

\subsection{Weighting Scale assembly}

Watch the following video:
\url{https://www.youtube.com/watch?v=QM5nMauuca8}

\subsection{Photos}
\begin{figure}[H]
    \centering
    
    \caption{Front view}
    \label{fig:immagine}
\end{figure}

\begin{figure}[ht]
\centering
\begin{minipage}{.5\textwidth} 
  \centering
  
  \caption{Top view}
  \label{fig:test1}
\end{minipage}%
\begin{minipage}{.5\textwidth} 
  \centering
  
  \caption{Top view}
  \label{fig:test2}
\end{minipage}
\end{figure}

\begin{figure}[H]
    \centering
    
    \caption{Bottom view}
    \label{fig:immagine}
\end{figure}

\begin{figure}[ht]
\centering
\begin{minipage}{.5\textwidth} 
  \centering
  
  \caption{Left side view}
  \label{fig:test1}
\end{minipage}%
\begin{minipage}{.5\textwidth} 
  \centering
  
  \caption{Right side view}
  \label{fig:test2}
\end{minipage}
\end{figure}

\begin{figure}[H]
    \centering
    
    \caption{Back view}
    \label{fig:immagine}
\end{figure}

\begin{figure}[H]
    \centering
    
    \caption{Back view}
    \label{fig:immagine}
\end{figure}

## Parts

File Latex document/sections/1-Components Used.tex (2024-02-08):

\section{Components Used}
\begin{figure}[H]

\begin{subfigure}{0.5\textwidth}
 
\caption{Battery 9V}
\label{fig:battery}
\end{subfigure}
\begin{subfigure}{0.5\textwidth}

\caption{Touch Button (HW-139)}
\label{fig:touchbutton}
\end{subfigure}

\begin{subfigure}{0.5\textwidth}
 
\caption{ATtiny or Arduino Nano}
\label{fig:board}
\end{subfigure}
\begin{subfigure}{0.5\textwidth}

\caption{HX711}
\label{fig:hx711}
\end{subfigure}
\caption{}
\end{figure}

The \textbf{9V battery} is used as a portable power source for the project.\\
\\
The \textbf{HW-139 touch button} is a component used for touch detection. It can be used as a tare button for resetting the scale.\\\\
The \textbf{ATtiny} or \textbf{Arduino Nano} are some examples of a microcontroller development board used for programming and controlling the scale and its components.  \\ 
\\
The \textbf{HX711} is used to amplify and convert the analog signal from the load cell into a digital one that can be read by the microcontroller.\\
\\

\begin{figure}[H]
\begin{subfigure}{0.5\textwidth}
 
\caption{I2C Screen}
\label{fig:i2c}
\end{subfigure}
\begin{subfigure}{0.5\textwidth}

\caption{Loadcell}
\label{fig:loadcell}
\end{subfigure}

\begin{subfigure}{0.5\textwidth}
 
\caption{ON-OFF Switch}
\label{fig:switch}
\end{subfigure}
\begin{subfigure}{0.5\textwidth}

\caption{PCB Board}
\label{fig:pcb}
\end{subfigure}
\caption{}
\end{figure}

\noindent
The \textbf{I2C 16x2 LCD display} is used to show information such as the measured weight or other relevant details. \\
\\
The \textbf{5KG load cell} is a weight sensor used to measure the weight of objects placed on the plate.\\
\\
The \textbf{HX711} is used to amplify and convert the analog signal from the load cell into a digital one that can be read by the microcontroller.\\
\\
The \textbf{PCB} (Printed Circuit Board) is used to connect and organize the electronic components in the project.\\

\begin{figure}[H]
\centering

 
\caption{Rubber supports}
\label{fig:support}

\end{figure}

\noindent 
\textbf{Rubber supports} needed to avoid sliding and suport the structure of the scale.\\

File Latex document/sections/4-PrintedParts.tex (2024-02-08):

\section{3D Printed Parts}

\begin{table}[h]
    \centering
    \begin{tabular}{|c|c|}
        \hline
        \centering
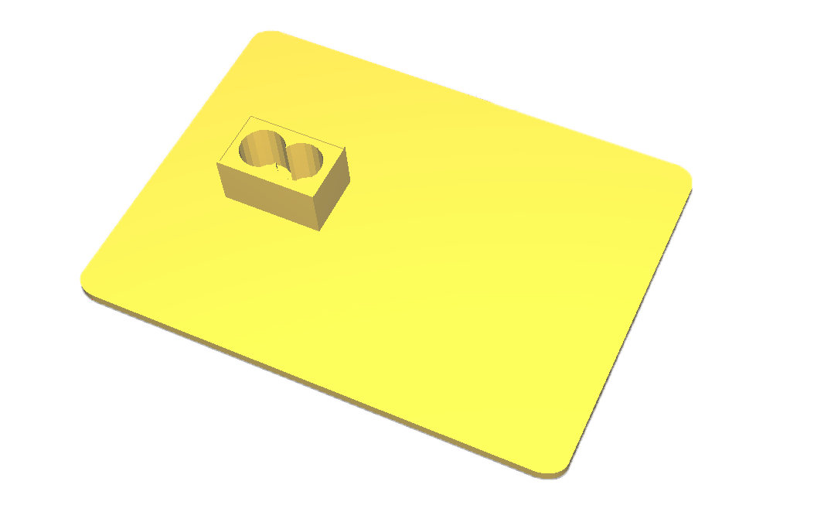
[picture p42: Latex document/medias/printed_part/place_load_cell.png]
         &
        \begin{minipage}[h]{0.60\linewidth}
            \caption*{\textbf{Platform}: where the objects to be weighed are placed.}
        \end{minipage} \\
        \hline
        \centering
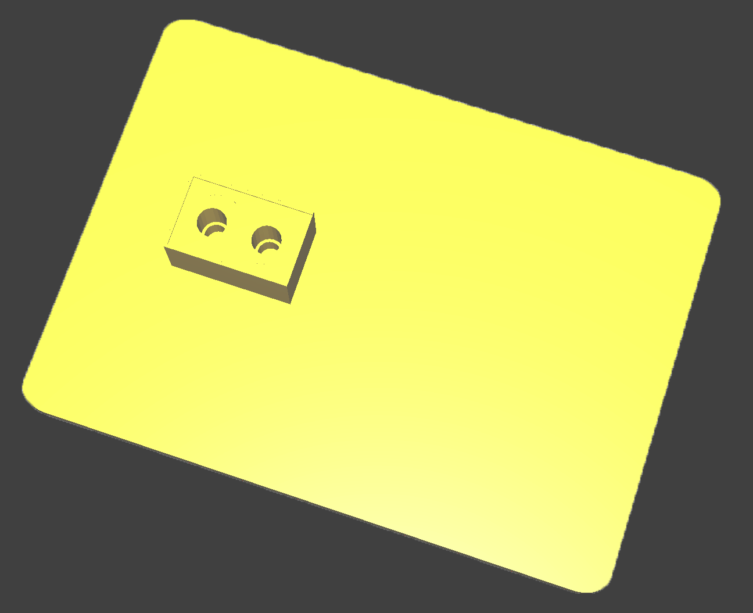
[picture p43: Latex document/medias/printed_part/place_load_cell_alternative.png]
         &
        \begin{minipage}[h]{0.60\linewidth}
            \caption*{\textbf{Alternative version of the Platform}: where the objects to be weighed are placed, with no screws in sight.}
        \end{minipage} \\
        \hline
        \centering
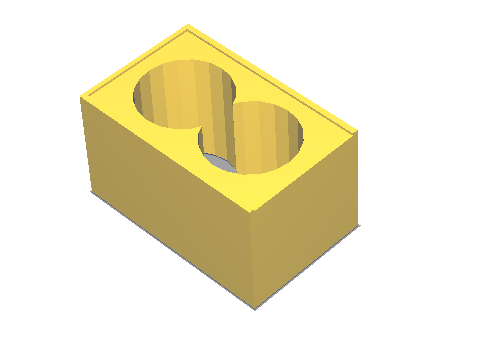
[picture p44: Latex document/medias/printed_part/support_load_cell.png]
         &
        \begin{minipage}[h]{0.60\linewidth}
            \caption*{\textbf{Load cell Support}: securely holds the load cell in place.}
        \end{minipage} \\
        \hline
        \centering
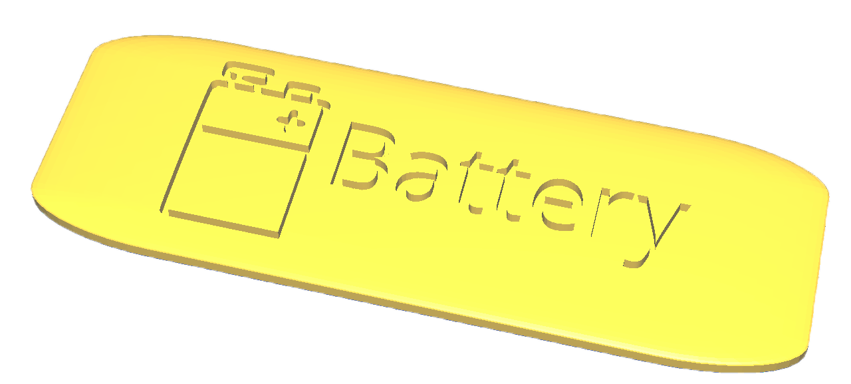
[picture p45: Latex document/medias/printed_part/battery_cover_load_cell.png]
         &
        \begin{minipage}[h]{0.60\linewidth}
            \caption*{\textbf{Battery cover}: to hide and protect the battery.}
        \end{minipage} \\
        \hline
        \centering
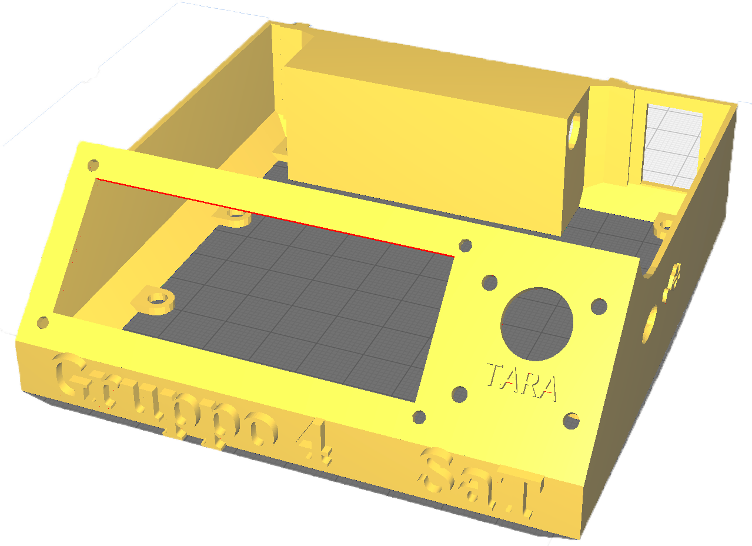
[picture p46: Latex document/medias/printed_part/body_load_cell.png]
         &
        \begin{minipage}[h]{0.60\linewidth}
            \caption*{\textbf{Body}: provides support to all the components and gives an aesthetically pleasing appearance.}
        \end{minipage} \\
        \hline
        \centering
         &
        \begin{minipage}[h]{0.60\linewidth}
            \caption*{\textbf{Support base}: was made from a 4mm thick wooden board, which was cut and drilled by a laser engraver.}
        \end{minipage} \\
        \hline
    \end{tabular}
\end{table}

\noindent These 3D-printed parts have been carefully designed to ensure proper functionality and compatibility with the electronic components used in the project.

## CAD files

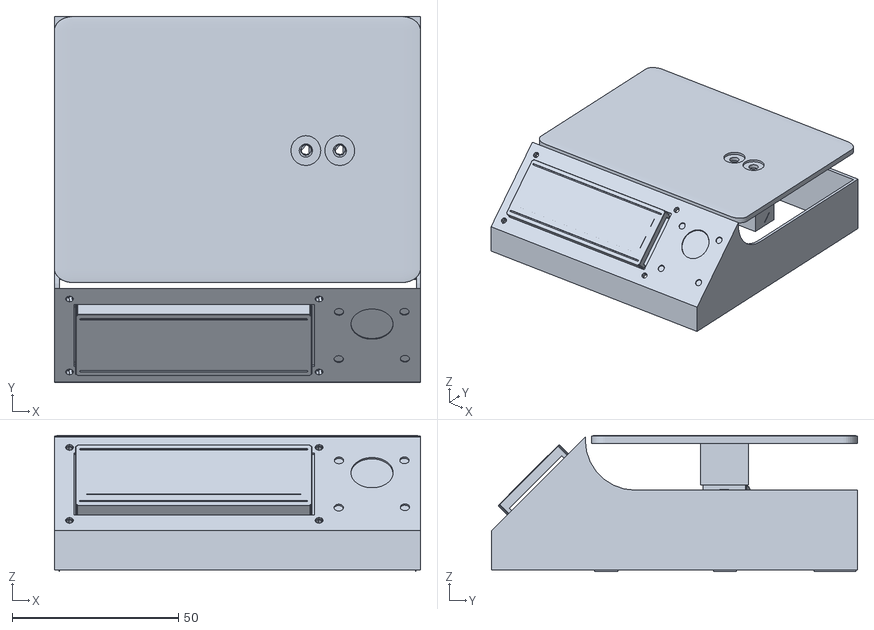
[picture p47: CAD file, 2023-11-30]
medias/Bilancino_gruppo_4.stl
110.0 x 110.0 x 41.0

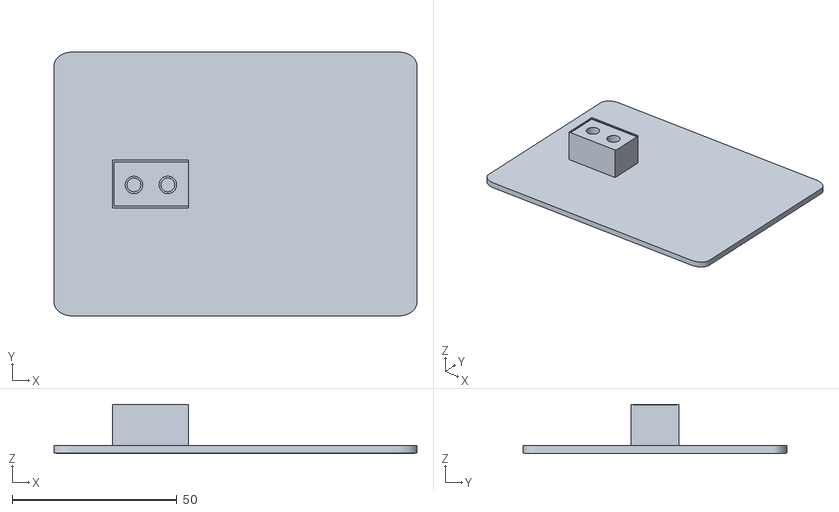
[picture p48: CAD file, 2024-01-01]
Printable 3D parts/Place_load_cell_brass_inserts.stl
110.0 x 80.0 x 15.0

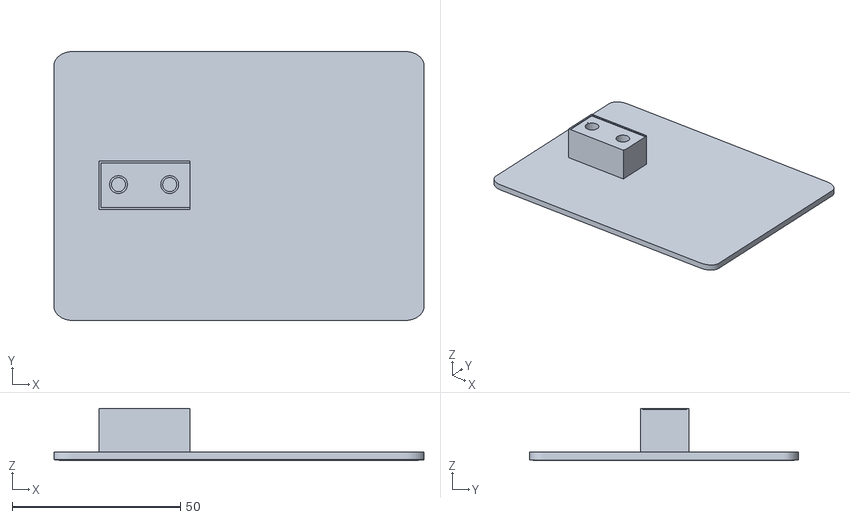
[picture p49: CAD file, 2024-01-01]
Printable 3D parts/Place_load_cell_brass_inserts_larger.stl
110.0 x 80.0 x 15.5

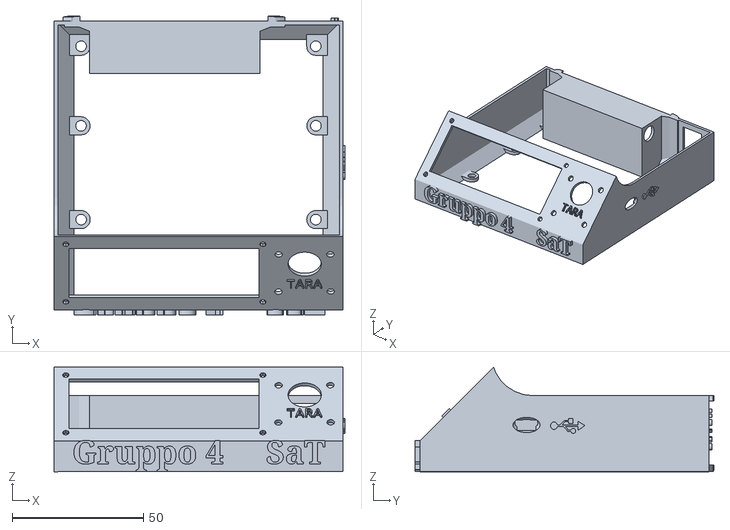
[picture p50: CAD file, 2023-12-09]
Printable 3D parts/Body_text_load_cell.stl
110.8 x 113.8 x 39.9

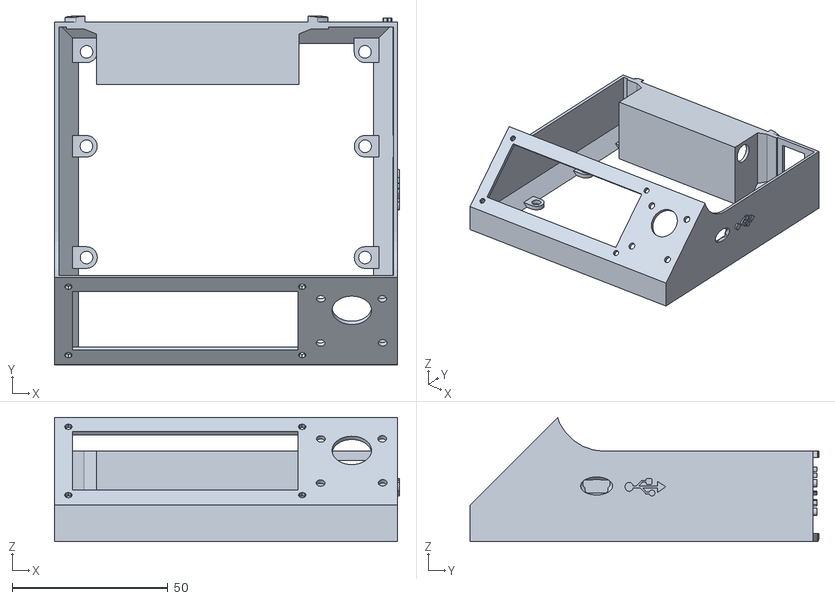
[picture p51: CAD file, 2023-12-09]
Printable 3D parts/Body_load_cell.stl
110.8 x 112.0 x 39.9

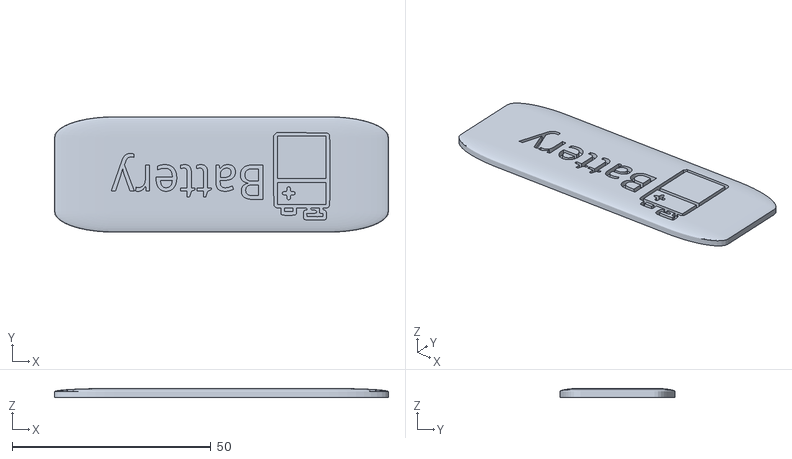
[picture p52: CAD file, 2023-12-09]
Printable 3D parts/Battery_cover_load_cell.stl
84.0 x 29.0 x 2.30

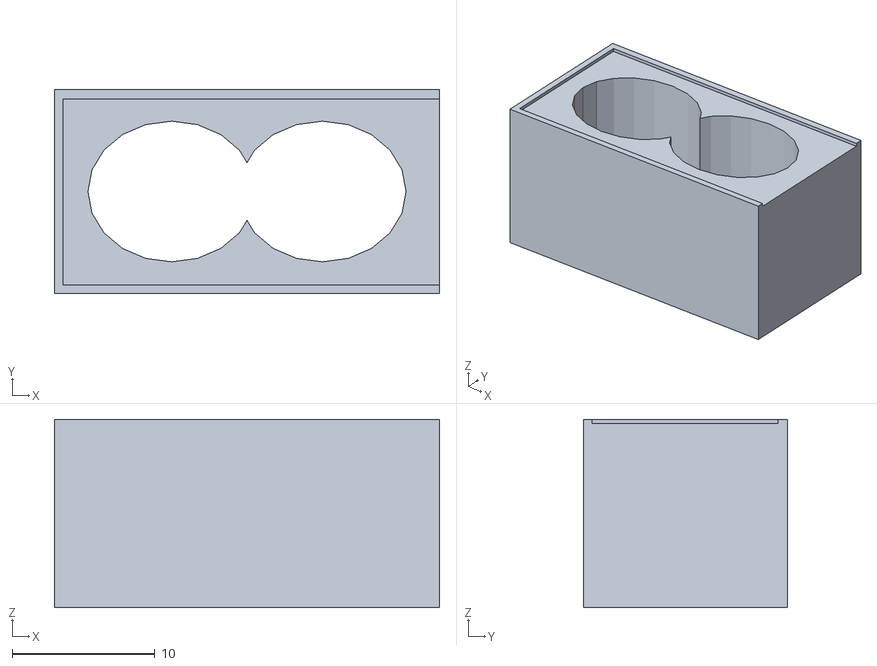
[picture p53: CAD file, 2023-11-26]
Printable 3D parts/Suppor_load_cell_larger.stl
27.0 x 14.3 x 13.2

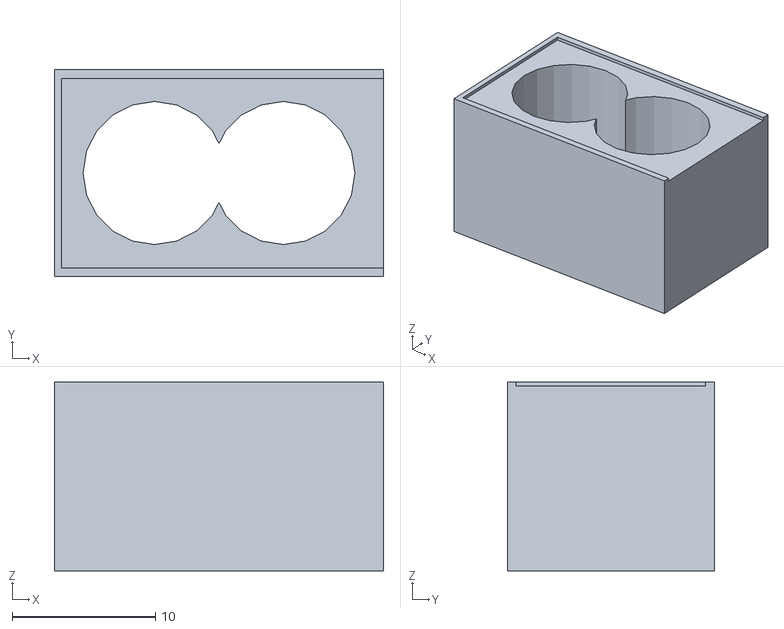
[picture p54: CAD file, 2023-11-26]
Printable 3D parts/Support_load_cell.stl
23.0 x 14.5 x 13.2

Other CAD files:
Printable 3D parts/Place_load_cell_larger.stl
Printable 3D parts/Place_load_cell.stl

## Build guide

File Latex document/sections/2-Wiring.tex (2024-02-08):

\section{Components Wiring}
The components are wired as follows:

\begin{figure}[h]
\centering

\caption{Schematic}
\end{figure}

\subsection{HX711 load cell amplifier}
\begin{itemize}
\item \texttt{LOADCELL\_DOUT\_PIN} is connected to pin 3 of the Arduino board.
\item \texttt{LOADCELL\_SCK\_PIN} is connected to pin 2 of the Arduino board.
\end{itemize}

\subsection{LCD display (I2C interface)}
\begin{itemize}
\item Address: 0x27
\item Columns: 16
\item Rows: 2
\end{itemize}

\subsection{Tare button}
\begin{itemize}
\item Connect one terminal of the button to a digital input pin of the Arduino board.
\item Connect the other terminal of the button to the ground (GND) pin of the Arduino board.
\item Optionally, add a pull-up resistor between the digital input pin and the 5V pin of the Arduino board to ensure stable button readings. (We implemented it, if you want to add it, you can modify it in declaration part)
\end{itemize}

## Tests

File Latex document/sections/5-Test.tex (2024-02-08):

\section{Test}

\begin{figure}[h]
\centering

\caption{Test with sample weights}
\end{figure}
\clearpage

\section{Calibration}

We are trying to calibrate this scale using an iterative method to find the calibration factor and the offset that minimize the error between the actual weight and the measured weight. To do this, you can use the following formula:

\[
\text{Actual weight} = \text{Measured weight} \times \text{Cf} + \text{Offset}
\]
\noindent
To calculate the error, we can use the following formula:

\[
\text{Error} = \sum_{i=1}^{n} (\text{Actual weight}_i - \text{Measured weight}_i \times \text{Cf} - \text{Offset})^2
\]
\noindent
Where $n$ is the number of weights used in each iteration.\\
To find the Cf and the Offset that minimize the error, we use the gradient method, which consists of changing the values of Cf and Offset according to the derivative of the error with respect to them, using the following formulas:

\[
\text{New Cf} = \text{Cf} - \alpha \frac{\partial \text{Error}}{\partial \text{Cf}}
\]

\[
\text{New Offset} = \text{Offset} - \alpha \frac{\partial \text{Error}}{\partial \text{Offset}}
\]
\noindent
Where $\alpha$ (also called learning rate) is a parameter that controls the convergence rate of the method. The value of $\alpha$ is chosen so that it is small enough to avoid swings, but large enough to reach the minimum in a few iterations.\\
To calculate the partial derivatives of the error, we need to use the following formulas:

\[
\frac{\partial \text{Error}}{\partial \text{Cf}} = -2 \sum_{i=1}^{n} (\text{Actual weight}_i - \text{Measured weight}_i \times \text{Cf} - \text{Offset}) \times \text{Measured weight}_i
\]

\[
\frac{\partial \text{Error}}{\partial \text{Offset}} = -2 \sum_{i=1}^{n} (\text{Actual weight}_i - \text{Measured weight}_i \times \text{Cf} - \text{Offset})
\]
\noindent
In reality, for the calculation of Cf and offset, we are using an empirical formula, that is, adding the error with a certain weight to the previously calculated values:

\[
\text{New Cf} = \text{Cf} - \beta \times \text{Error}
\]

\[
\text{New Offset} = \text{Offset} - \beta \times \text{Error}
\]
\noindent
Where $\beta$ is a kind of learning rate, suitably tuned to get progressively better results.

\subsection{Procedure}

Wanting to go through the entire calibration process in depth:

\begin{itemize}
\item We prepared 6 iterations, with gradually smaller ranges, using sample weights:

\begin{tabular}{|c|c|c|}
\hline
\textbf{Iteration} & \textbf{Range} & \textbf{Increment} \\
\hline
0 & 0g-100g & 10g \\
1 & 0g-50g & 5g \\
2 & 0g-5.5g & 0.5g \\
3 & 0g-2g & 0.2g \\
4 & 0g-0.5g & 0.05g \\
5 & 0g-0.2g & 0.02g \\
\hline
\end{tabular}

\item We placed each weight for 5 points of the plate (center and the four corners)

\item Using MATLAB, we used a regression algorithm to fit the collected data The slope of the regression line represents the calibration factor and the intercept represents the offset, using the Euclidean norm (norm 2) to evaluate the error.

\item Last we used the data calculated by calibration, using it when compiling the microcontroller program.
\end{itemize}

\subsection{MATLAB pseudocode}

\begin{verbatim}
clear the workspace and the screen
reset the serial devices

set the number of objects
create a matrix of zeros to store the measures
create two vectors of zeros to store the weights

create and open a serial connection with the scale

wait until the scale is ready

for each object
    print a new line
    for each position from 1 to 5
        if the position is 1 (middle)
            ask the user to enter the known weight and place the object in the middle
            validate the input
            store the known weight in the vector x
            print a new line
        else if the position is 2 (bottom left)
            ask the user to place the object in the bottom left
        else if the position is 3 (top left)
            ask the user to place the object in the top left
        else if the position is 4 (top right)
            ask the user to place the object in the top right
        else if the position is 5 (bottom right)
            ask the user to place the object in the bottom right
        send a signal to the scale
        read the measured value from the scale
        store the measured value in the matrix measures
        print the measured value
    end for
end for

close and delete the serial connection
reset the serial devices

for each object
    calculate the average of the measures for that object
    store the average in the vector y
end for

create a table with the vectors x and y
save the table as a text file
save the table as a csv file

find the coefficients of the best fitting line for the data
the slope is the calibration factor
the intercept is the offset
evaluate the line at the known weights
compute the error vector
compute the error norm
print the error

create and clear a figure
plot the data as green circles
plot the line as a solid line
\end{verbatim}

\subsection{Stop condition}

For calibration, we have to find the right compromise to make the regression line fit, considering that we have to use a smaller and smaller range of weights until we arrive at a measurement that is not fouled by noise in such a way that the behavior of the scale is no longer linear. We found that up to the third iteration we still have linear behavior, with a larger error than in the second iteration, as the distance between the points and the line increases. Using a smaller range would mean that the measurements are greatly affected by noise, increasing the error as we try to fit a line into a nonlinear set of points.

\subsubsection{Iteration 0}

\begin{figure}[ht]
\centering
\begin{minipage}{.6\textwidth} % 60% della larghezza del testo
  \centering
  
  \captionof{figure}{Regression}
  \label{fig:test1}
\end{minipage}%
\begin{minipage}{.4\textwidth} % 40% della larghezza del testo
  \centering
  
  \captionof{figure}{Workspace}
  \label{fig:test2}
\end{minipage}
\end{figure}

\subsubsection{Iteration 1}

\begin{figure}[H]
\centering
\begin{minipage}{.6\textwidth} % 60% della larghezza del testo
  \centering
  
  \captionof{figure}{Regression}
  \label{fig:test3}
\end{minipage}%
\begin{minipage}{.4\textwidth} % 40% della larghezza del testo
  \centering
  
  \captionof{figure}{Workspace}
  \label{fig:test4}
\end{minipage}
\end{figure}

\subsubsection{Iteration 2}

\begin{figure}[ht]
\centering
\begin{minipage}{.6\textwidth} % 60% della larghezza del testo
  \centering
  
  \captionof{figure}{Regression}
  \label{fig:test5}
\end{minipage}%
\begin{minipage}{.4\textwidth} % 40% della larghezza del testo
  \centering
  
  \captionof{figure}{Workspace}
  \label{fig:test6}
\end{minipage}
\end{figure}

\clearpage

\subsubsection{Iteration 3}

\begin{figure}[ht]
\centering
\begin{minipage}{.6\textwidth} % 60% della larghezza del testo
  \centering
  
  \captionof{figure}{Regression}
  \label{fig:test7}
\end{minipage}%
\begin{minipage}{.4\textwidth} % 40% della larghezza del testo
  \centering
  
  \captionof{figure}{Workspace}
  \label{fig:test8}
\end{minipage}
\end{figure}

\subsubsection{Iteration 4}

\begin{figure}[ht]
\centering
\begin{minipage}{.6\textwidth} % 60% della larghezza del testo
  \centering
  
  \captionof{figure}{Regression}
  \label{fig:test9}
\end{minipage}%
\begin{minipage}{.4\textwidth} % 40% della larghezza del testo
  \centering
  
  \captionof{figure}{Workspace}
  \label{fig:test10}
\end{minipage}
\end{figure}

\begin{quote}
In this graph, it can be seen that variations on the order of hundredths of a gram are not appreciable, as the noise mat is of the same order of magnitude, so it makes the regression results much worse when calculating Cf and offset. Taken this into account, the 5th iteration wouldn't have much meaning.
\end{quote}

\clearpage

\subsection{Results}

In truth, already the first iteration returns us a plausible value of Cf, but this can be further improved. The same applies to the offset as well. The best result was achieved at the second iteration, when the range of values is small, but the variations between weights are still appreciable. In addition, we noticed that when the variation falls below 0.5 grams it starts to feel particularly noisy, so the measurements are more degraded. This, counterintuitively gives worse results, and as can be seen from the third iteration, will give a larger error and worse Cf and offset values than those calculated before.

\section{Noise}

The purpose of the noise test was to evaluate the accuracy and stability of the balance without any weights on it. We expected the balance to output zero or very small values when no weight was applied. However, due to various sources of noise, such as electrical interference, mechanical vibrations, or environmental factors, the balance might output some non-zero values.
\\
To perform the noise test, we collected 100 samples from the balance using Matlab, receiving a floating-point number representing the weight in grams from the scale. We repeated this process 100 times and stored the values in a vector n. We also saved the data in a table T and exported it to a text file and a csv file.
\\
We then analyzed the data using Matlab. We calculated the mean and the standard deviation of the vector n to get an estimate of the average noise level and the noise variance. We also plotted the frequency spectrum of the vector n using the discrete Fourier transform (DFT) to identify any dominant frequency components in the noise.
\\
The results of the noise test are shown below. The mean of the vector n is 0.12 g and the standard deviation is 0.07 g. This means that the balance has a very low noise level and a high accuracy. The frequency spectrum of the vector n shows that the noise is mostly random and does not have any significant peaks. This means that the balance is stable and does not suffer from any periodic disturbances.

\subsection{MATLAB pseudocode}

\begin{verbatim}
clear the workspace and the screen
reset the serial devices

Set N to 100
Create a vector of N elements, initialized to zero

create and open a serial connection with the scale

wait until the scale is ready

For each element of the vector
    Receive a numeric value from the device
    Save the value in the vector and print it on the screen
End for

Compute the DFT

Compute the mean and the standard deviation of the original vector
\end{verbatim}

\section{Repeatability}

Like any instrument, electronic scales can suffer from repeatability problems. This means that when the same load is measured multiple times, the result is not always exactly the same. To find out the repeatability of the instrument, a repeatability test is performed.
\\
The repeatability test is performed by replacing the same load at the same point on the weighing plane (to avoid any eccentricity error) several times. The test must be performed under identical and constant conditions and with identical handling.
\\
The calibration weight used should have a size as close as possible to the maximum range of the instrument. Often a repeatability test is performed with a single load, but it can also be performed with different load values, separately.
\\
A repeatability test is normally performed by repeating the measurement at least 5 times in a row. We did two tests:\\

\begin{figure}[ht]
\centering
\begin{minipage}{.5\textwidth} % 60% della larghezza del testo
  \centering
  
  \captionof{figure}{Test 1}
  \label{fig:test1}
\end{minipage}%
\begin{minipage}{.5\textwidth} % 40% della larghezza del testo
  \centering
  
  \captionof{figure}{Test 2}
  \label{fig:test2}
\end{minipage}
\end{figure}

\noindent In the repeatability test, the instrument is first zeroed, then the load is placed on the plate and the indication is recorded once stabilized. Then the load is removed and the zero indication is checked and zeroed if necessary. Then the load is replaced and so on. For a scale with multiple fields / divisions, a test weight below the first range should be sufficient.

\clearpage

\subsection{MATLAB pseudocode}

\begin{verbatim}
clear the workspace and the screen
reset the serial devices

Set N to 5
Create a vector of N elements, initialized to zero
Ask the user to remove any object from the scale

create and open a serial connection with the scale

wait until the scale is ready

For each element of the vector
    Ask the user to place the object on the scale
    Receive a numeric value from the device
    Save the value in the vector and print it on the screen
    Ask the user to remove the object from the scale
End for

Close and delete the serial connection

Compute the mean and the standard deviation of the original vector
\end{verbatim}
\clearpage

\section{Eccentricity}

Eccentricity tests are performed on weighing instruments to measure how the position of the load affects the accuracy and repeatability of the readings. The principle of the test is to compare the indications of the instrument when the same load is applied at different locations on the load receptor. The locations are chosen according to the shape and the number of support points of the load receptor, following the standards OIML R76 and EN 45501. The test load should be at least one third of the maximum capacity of the instrument, and preferably a single load, to ensure the consistency of the center of gravity.\\
\begin{figure}[h]
    \centering
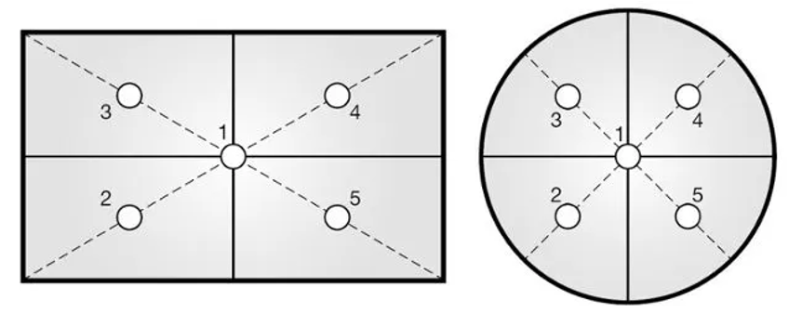
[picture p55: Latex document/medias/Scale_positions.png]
    
    \caption{Sample's positions}
    \label{fig:enter-label}
\end{figure}
\\
The test procedure consists of placing the test load at the center of the load receptor and recording the indication. Then, the load is moved to four other locations, usually at the corners or the edges of the load receptor, and the indications are recorded again. The load is then returned to the center and the indication is checked for any drift. The zero of the instrument may be verified and adjusted between each location, if needed. Alternatively, the instrument may be tared when the load is at the center, to make the differences between locations more visible. 
\clearpage

%inserire immagine 'eccentricity' e descrizione in forma tabellare 
\begin{figure}[h]
    \centering
    
    \caption{Workspace}
    \label{fig:enter-label}
\end{figure}

\noindent The test is considered passed if the differences between the indications at different locations are within the permissible errors specified by the standards or the manufacturer. The differences are also used to calculate the eccentricity error, which is the maximum deviation of the indication from the arithmetic mean of all indications. The eccentricity error is an important parameter to evaluate the performance and the quality of the weighing instrument.

\subsection{MATLAB pseudocode}

\begin{verbatim}
clear the workspace and the screen
reset the serial devices

Set N to 5
Create a vector of N elements, initialized to zero
Ask the user to remove any object from the scale

create and open a serial connection with the scale

wait until the scale is ready

For each position of the scale
    Ask the user to place the object on the scale
    Receive a numeric value from the device
    Save the value in the vector and print it on the screen
    Ask the user to remove the object from the scale
End for

Close and delete the serial connection

Compute the mean and the standard deviation of the original vector

Save the data in a table with two columns: measured weight and error
\end{verbatim}

\section{Hysteresis}

Hysteresis refers to the difference in a system’s output when a specific input is approached from increasing and decreasing directions. In weighing tests, it’s crucial not to overshoot or undershoot the load to accurately identify hysteresis. The instrument should be calibrated with increasing and decreasing points, approaching each test point with increasing or decreasing weight respectively.
\\
Multiple points throughout the instrument’s measurement range are used to reveal any linearity issues, which means the instrument does not measure equally accurate throughout its range. Even if the zero and full span are correct, there may be errors in the middle of the range, referred to as linearity errors, or non-linearity.
\\
The purpose of a weighing test is to test the calibrated accuracy of the weighing instrument across its entire range, in several steps, with increasing and decreasing weight. Typically, 5 to 10 different loads (test points) are used, and each range must be calibrated separately in multi-range instruments.

\subsection{MATLAB pseudocode}

\begin{verbatim}
clear the workspace and the screen
reset the serial devices

Set N to 5
Create a vector of 2*N elements, initialized to zero
Ask the user to remove any object from the scale

create and open a serial connection with the scale

wait until the scale is ready

For each measurement, up to N
    ask the user to enter the known weight (ascending order)
    Receive a numeric value from the device
    Save the value in the vector and print it on the screen
    Ask the user to remove the object from the scale
End for

For each measurement, for N+1 up to 2*N
    ask the user to enter the known weight (descending order)
    Receive a numeric value from the device
    Save the value in the vector and print it on the screen
    Ask the user to remove the object from the scale
End for

Close and delete the serial connection

plot the data
\end{verbatim}

\begin{quote}
\textbf{Note:} Try not to keep the scale turned on for a very long time, since it may lose precision due to the heating of the components.
\end{quote}

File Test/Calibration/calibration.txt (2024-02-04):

Known weight,Measured weight
0,-0.012
0.01,-0.004
0.02,-0.004
0.03,0.008
0.04,0.04
0.05,0.034
0.06,0.04
0.07,0.046
0.08,0.034
0.09,0.03
0.1,-0.032

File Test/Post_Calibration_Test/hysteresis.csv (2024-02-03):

Known weight | Measured weight
1.1 | 1.05
1.2 | 1.21
1.3 | 1.3
1.4 | 1.38
1.5 | 1.51
1.5 | 1.46
1.4 | 1.42
1.3 | 1.3
1.2 | 1.19
1.1 | 1.09

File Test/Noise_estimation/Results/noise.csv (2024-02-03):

Noise
0.01
0
-0.01
-0.03
-0.04
-0.05
0.02
0.04
-0.01
-0
0
0.05
-0.02
-0
-0.03
-0.02
-0.03
0.01
-0.05
0
-0
-0.03
0.02
0.04
0.02
-0.02
0.02
0.01
0.02
-0.06
0.01
0.02
-0.02
-0.02
0.03
-0.04
0.01
0.01
-0.02
0
-0.01
-0.02
-0.02
-0.03
-0.01
-0.01
-0.03
-0.02
-0.02
-0
-0.02
0.02
-0.03
-0.03
0.04
-0.02
-0
0.04
-0.03
-0.01
-0
-0.03
-0.02
0.01
-0.04
0
-0.02
-0.03
-0.04
0
0.03
0.02
-0.08
-0.01
-0.01
-0.04
-0
-0.03
-0.03
0
-0.03
-0.02
0.02
0.02
-0.01
-0.01
0
0.02
-0.01
-0.01
0.06
-0.01
0.01
-0
0.03
-0.01
-0.03
0.01
0.01
-0.01

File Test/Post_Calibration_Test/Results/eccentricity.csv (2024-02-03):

Measured weight | Error
99.98 | 0.019999999999996
100.09 | -0.0900000000000034
100.13 | -0.129999999999995
100.01 | -0.0100000000000051
100.03 | -0.0300000000000011

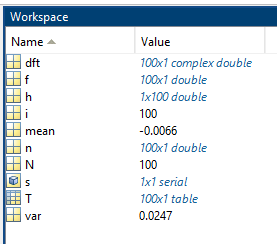
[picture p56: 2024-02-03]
Latex document/medias/test/noise/noise_results.png

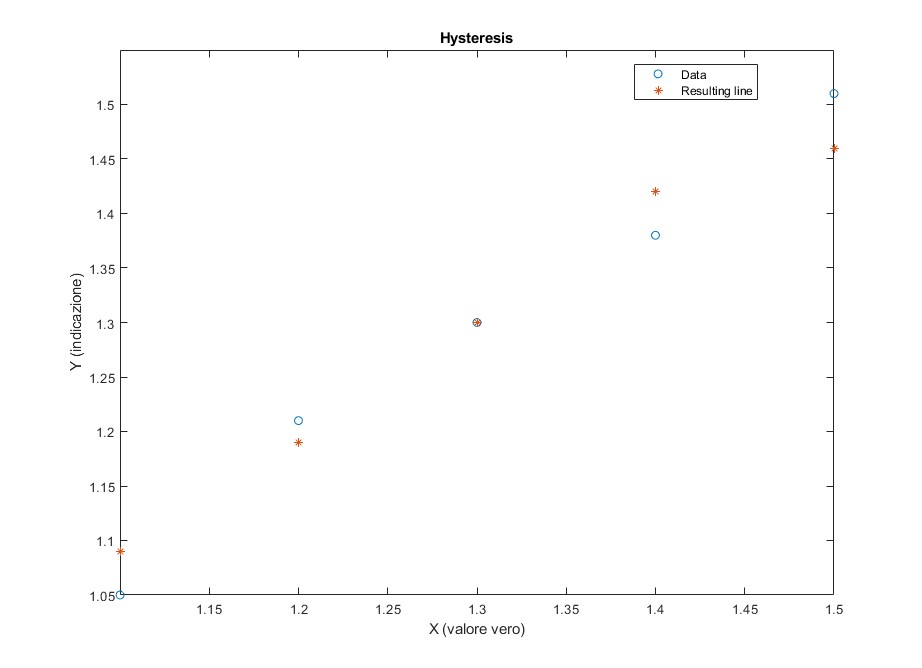
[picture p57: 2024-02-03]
Latex document/medias/test/post/hysteresis_results_plot.jpg

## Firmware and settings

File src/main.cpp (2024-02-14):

/***************************************************
 * Bilancia SaT - Weight Measurement
 *
 * Contributors:
 * - Vincenzo Pio Florio
 * - Francesco Stasi
 * - Simona Vatinno
 * - Davide Tonti
 * - Giovanni Zito
 *
 * This project utilizes an HX711 load cell
 * amplifier, an LCD display, and a tare button to
 * create a weighing system. The program continuously
 * reads the weight and displays it on both the Serial
 * Monitor and the LCD screen. The tare button allows
 * for resetting the scale to zero.
 ***************************************************/

#include <Arduino.h>
#include <Wire.h> 
#include <LiquidCrystal_I2C.h>
#include <HX711.h>

// HX711 circuit wiring
const int LOADCELL_DOUT_PIN = 4;
const int LOADCELL_SCK_PIN = 3;

// HX711 constructor
HX711 scale;

// LCD constructor
LiquidCrystal_I2C lcd(0x27, 16, 2);

// Weight setup
float calibration_factor = 471.42068;
float offset = 429430202;
float units;

// Declaring button for tare
int buttonPin = 5;

void setup() {
  // Initialize Serial Monitor
  Serial.begin(115200);

  // Print contributors
  Serial.println("-------------------------------");
  Serial.print("Bilancia SaT - Gruppo 4\n");
  Serial.println("-------------------------------");
  Serial.println("Contributors:");
  Serial.println("- Vincenzo Pio Florio");
  Serial.println("- Francesco Stasi");
  Serial.println("- Simona Vatinno");
  Serial.println("- Davide Tonti");
  Serial.println("- Giovanni Zito");
  Serial.println("-------------------------------");

  // Initialize LCD
  lcd.init();
  lcd.backlight();
  Serial.println("LCD initialized\n");

  // Initialize button
  pinMode(buttonPin, INPUT_PULLUP);
  Serial.println("Button initialized\n");

  // Initialize library with data output pin, clock input pin and gain factor.
  scale.begin(LOADCELL_DOUT_PIN, LOADCELL_SCK_PIN);
  Serial.println("Scale initialized\n");

  // Raw data reading
  // Serial.print("Read: ");
  // Serial.print(scale.read());
  // Serial.print("  ");
  // Serial.print(scale.read_average(20));
  // Serial.println("  ");
  // Serial.println("");

  delay(300);

  // Calibration factor reading
  scale.set_scale(calibration_factor);
  Serial.print("Calibration factor: ");
  Serial.println(scale.get_scale());
  Serial.println("");

  scale.set_offset(offset);

  // Tare reading
  //scale.tare(); //Reset the scale to 0
  Serial.println("Tare initialized\n");
  Serial.println("Readings:\n");
}

/**
 * The main loop function that runs repeatedly in the program.
 * It reads the change in weight from the scale, prints it to the Serial monitor and LCD,
 * and performs a tare operation if the button is pressed.
 */
void loop() {
  // Read the change in weight
  units = scale.get_units(10);

  if(abs(units) < 0.05){
    units = abs(units);
  }

  // Print the change in weight
  Serial.print("Weight: ");
  Serial.print(units,5);
  Serial.println(" grams");
  
  // Print the change in weight on the LCD
  lcd.clear();
  lcd.setCursor(0, 0);
  lcd.print("Weight: ");
  lcd.print(units);
  lcd.print(" g");
  lcd.setCursor(0, 1);
  lcd.print("      ");


  // Tare the scale
  if (digitalRead(buttonPin) == HIGH) {
    scale.tare();
    Serial.println("Tare");
    lcd.setCursor(0, 1);
    lcd.print("Tare");
  }
}

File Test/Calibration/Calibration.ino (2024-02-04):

#include <Arduino.h>
#include <Wire.h> 
#include <LiquidCrystal_I2C.h>
#include <HX711.h>

// HX711 circuit wiring
const int LOADCELL_DOUT_PIN = 4;
const int LOADCELL_SCK_PIN = 3;

// HX711 constructor
HX711 scale;

// LCD constructor
LiquidCrystal_I2C lcd(0x27, 16, 2);


// Weight setup
float units;

void setup() {
  // Initialize Serial Monitor
  Serial.begin(115200);
  lcd.init();
  lcd.backlight();
  lcd.setCursor(0, 0);
  lcd.print("reset");

  // Initialize library with data output pin, clock input pin and gain factor.
  scale.begin(LOADCELL_DOUT_PIN, LOADCELL_SCK_PIN);

  scale.set_offset(4294929923); 
  scale.set_scale(450.622436);
  scale.tare(20);

  Serial.print("Setup done");
}

void loop() {
  units = scale.get_units(10); 
  if(Serial.available()){
    if(Serial.read() == 'a'){
      lcd.clear();
      Serial.println(units);
      lcd.setCursor(0, 0);
      lcd.print(units);
    }
  }
}

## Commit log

2023-11-26 Hotfixes
    -Fixed a button issue (LOW instead of HIGH)
    -Fixed Serial Output display
    [main.cpp]
2023-11-26 General Hotfixes
    [Body_load_cell.stl, Body_text_load_cell.stl, Place_load_cell.stl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]
2023-11-26 Changed Board
    -Added support for ESP8266
2023-11-30 New folder "medias"
    added:
    Fritzing schematic
    file .stl of 3D model
    [Bilancino_gruppo_4.stl, load_cell_schematic.fzz]
2023-12-09 Update of 3D printing files
    3D print files have been updated:
    -Body_text_load_Cell
    -Body_load_Cell
    -Battery_cover_load_Cell
    Now the model has a compartment with magnetic closure for the battery, and direct serial communication is possible with the Arduino Nano.
    [Battery_cover_load_cell.stl, Body_load_cell.stl, Body_text_load_cell.stl]
2023-12-14 Changed board
2024-01-01 New 3D printable parts
    [Place_load_cell_brass_inserts.stl, Place_load_cell_brass_inserts_larger.stl]
2024-02-01 Test added
    [eccentricity.csv, hysteresis.csv, noise.csv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]
2024-02-01 Added calibration tests
2024-02-02 Rename Beamex White Paper - Weighing scale calibration copia.pdf to Beamex White Paper - Weighing scale calibration.pdf
2024-02-02 Fixed calibration script
2024-02-02 Update README.md
    Added Calibration to README
2024-02-03 Noise estimation results
    [noise.csv]
2024-02-03 fixed eccentricity files
    [eccentricity.csv]
2024-02-03 Repeatability fixed files
    [repeatability.csv]
2024-02-03 hysteresis, nonLinearity fixed files
    [hysteresis.csv]
2024-02-04 grid for 3d printed parts
2024-02-04 Fixed plate name
2024-02-08 Laser cutting of the support base
